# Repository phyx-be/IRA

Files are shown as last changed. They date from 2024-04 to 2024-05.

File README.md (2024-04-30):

# IRA
IRA, named after the [mother of the stars in Polynesisn mythology](https://en.wikipedia.org/wiki/Ira_(mythology)) is the controller for the lights at [Fri3d Camp](https://fri3d.be/) based around the ESP-WROVER-32. The design was made to fit in the [Hammond 1593ARTBU](https://www.hammfg.com/part/1593ARTBU?referer=741) housing.

## REV 00
Initial prototype of the IRA controller.

## REV 01
Production version of the IRA, most of the boards have 2 buffered outputs, 20 have been fitted with RS-485 hardware for DMX. Changes compared to REV 00 : Added clearance around screw holes, added text around switches and increased documentation on silk layers.

## REV 02
Modified version of the 01 revision with less free IO but 8 buffered outputs for WS2812-style adressable LEDs. 12V power has been upgraded to a switching power supply and 2 soldered threaded standoffs are added which can be used as power distribution points. The expansion header has all the pins for I²C or I²S expansions. Onboard I²C has been removed and a [Tag-Connect](https://www.tag-connect.com/product/tc2030-idc-nl) programming header was added. 

There are various stuffing options : 
- Default : 12V or 5V Power, 8 buffered outputs
- Default DMX : 12V or 5V Power, 8 buffered outputs, DMX
- Minimal : 5V Power, 2 buffered outputs
- Minimal DMX : 5V Power, 2 buffered outputs, DMX
- Development : 12V or 5V Power, 8 buffered outputs, DMX, USB Serial convertor with USB-C connector

# Pictures

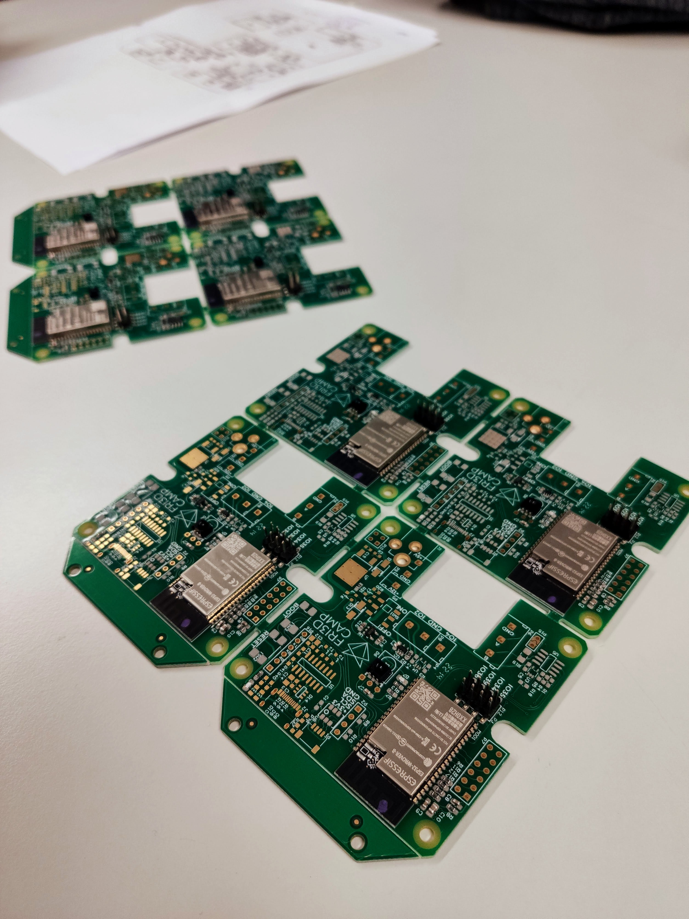
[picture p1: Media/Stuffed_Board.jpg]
IRA Stuffed Boards

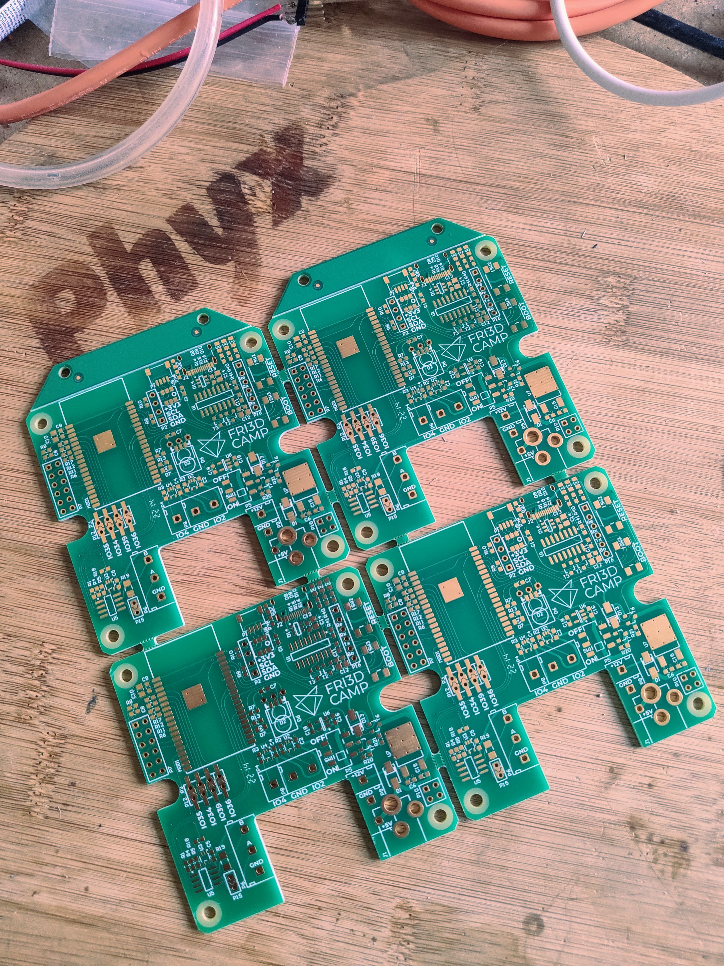
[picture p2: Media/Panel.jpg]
IRA Panel

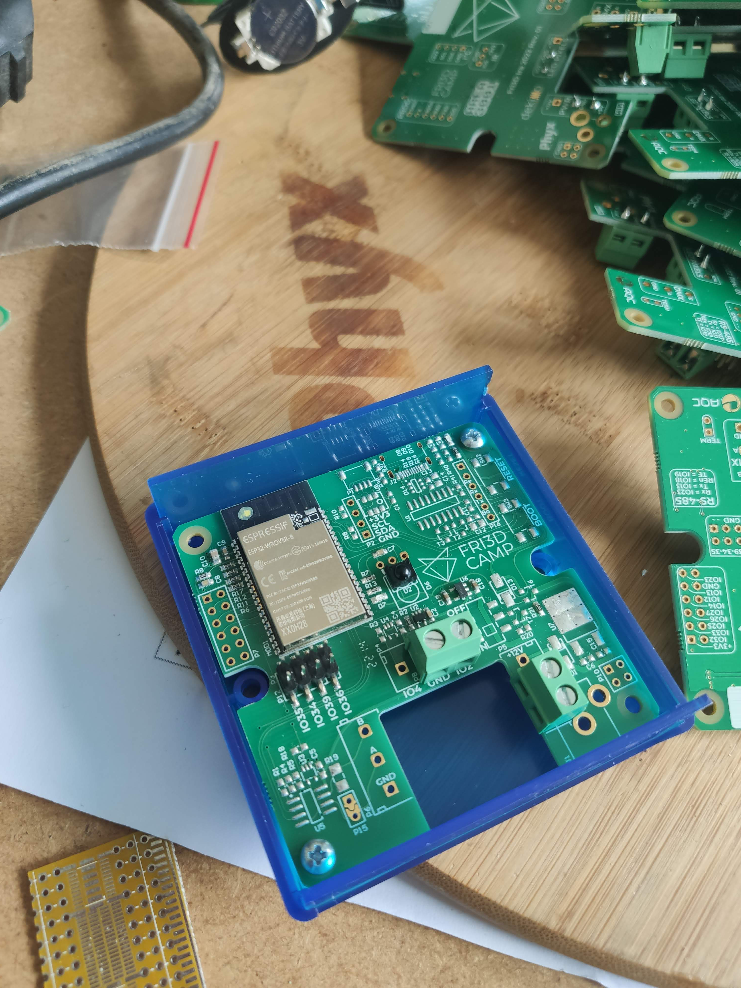
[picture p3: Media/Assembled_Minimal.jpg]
IRA Assembled

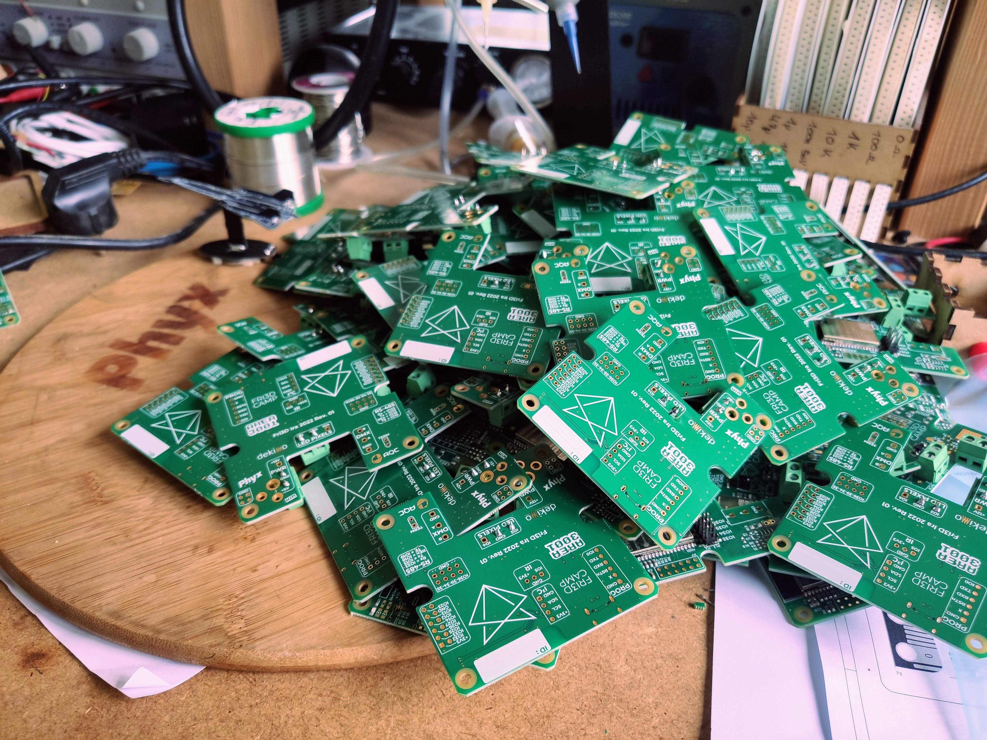
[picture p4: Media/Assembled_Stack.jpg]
IRA Assembled Stack


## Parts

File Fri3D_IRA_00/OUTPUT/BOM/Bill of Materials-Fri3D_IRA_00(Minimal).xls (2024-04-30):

Bill of Materials |  |  | Fri3D Ira 2020
Project: |  | Fri3D_IRA_00.PrjPcb
Revision: |  | 00
Variant: |  | Minimal
Creation Date: | 18/09/2021 | 11:14
Print Date: | 2021-09-18 | 11:14:57
Footprint | Comment | LibRef | Designator | Value | Description | Supplier 1 | Supplier Part Number 1 | Supplier 2 | Supplier Part Number 2 | Supplier 3 | Supplier Part Number 3 | Quantity
C0603_N |  | CAP # 100nF 16V 0603 | C2, C7, C8, C9 | 100nF 16V | CAP # 100nF 16V 0603 | LCSC | C282519 |  |  | Generic | 100nF 16V 0603 X7R | 4
C0805_N |  | CAP # 10uF 10V 0805 | C10 | 10uF 10V | CAP # 10uF 10V 0805 | Farnell | 2320859 | LCSC | C17024 | Generic | 10uF 10V 0805 X7R | 1
C0603_N |  | CAP # 1uF 16V 0603 | C18, C19 | 1uF 16V | CAP # 1uF 16V 0603 | Farnell | 2320814 |  |  | Generic | 1uF 16V 0603 X7R | 2
CHAU_ZIRM-5042B-42-Z2 | ZIRM-5042B-42-Z2 Infrared Receiver 38 kHz 45° 2.7-5.5V 940nm | PHO IR Rx 940nm ZIRM-5042B-42-Z2 | D2 | ZIRM-5042B-42-Z2 | PHO IR Rx 940nm ZIRM-5042B-42-Z2 | LCSC | C575386 |  |  |  |  | 1
LED_0805_RD | Default 0805 Red LED | LED # Red 0805 | D7 |  | LED # Red 0805 | Farnell | 2099236 |  |  |  |  | 1
LED_0805_GR | Default 0805 Green LED | LED # Green 0805 | D10 |  | LED # Green 0805 | Farnell | 2099239 |  |  |  |  | 1
ESP-WROVER-32 | ESP-32 based ESP-WROVER-32 | WiFi # MOD ESP-WROVER-32 | MOD1 | ESP-WROVER-32 | WiFi # MOD ESP-WROVER-32 | Espressif | ESP-WROVER-32 |  |  |  |  | 1
HDR2X4 | Header 4x2 | Pin Header 2.54mm dual row 8way | P3 |  | Pin Header 2.54mm dual row 8way |  |  |  |  |  |  | 1
TERM_BLK-0508-2-90 | 2 Way Screw HDR 5,08mm | Terminal Block 5.08mm 2way | P8, P9 | PM5.08/2/90 | Terminal Block 5.08mm 2way | Farnell | 1131853 |  |  |  |  | 2
SOLDER_SW_V_1MM | Easy to solder connection | SOLDER SW V 1MM | P11, P17, P18, P19 | NO BOM | SOLDER SW V 1MM |  |  |  |  |  |  | 4
HDR1X6 | Header 6 | Pin Header 2.54mm 6way | P16 |  | Pin Header 2.54mm 6way |  |  |  |  |  |  | 1
R0603_N |  | RES # 1K2 0603 | R2, R13, R16 | 1K2 | RES # 1K2 0603 | Farnell | 2446592 |  |  | Generic | 1K2 1% 0603 | 3
R0603_N |  | RES # 5K1 0603 | R7, R8 | 5K1 | RES # 5K1 0603 | Farnell | 2845922 | LCSC | C112314 | Generic | 5K1 1% 0603 | 2
R0603_N |  | RES # 0R 0603 | R21 | 0R | RES # 0R 0603 | Farnell | 2447743 |  |  | Generic | 0R 1% 0603 | 1
TI_DCK_R-PDSO-G5 | SN74AHCT1G125DCKR Buffer, Tri-State, 4.5V to 5.5V | BUF # 1 SN74AHCT1G125DCKR | U2 | SN74AHCT1G125DCKR | BUF # 1 SN74AHCT1G125DCKR | LCSC | C151417 | LCSC | C350557 |  |  | 1
SOT23-5 | 3V3 LDO 700mA 50mV | LDO # 3V3 XC6210B33 | U6 | XC6210B332MR | LDO # 3V3 XC6210B33 | Farnell | 1057803 | LCSC | C47719 |  |  | 1
 |  |  |  |  |  |  |  |  |  |  |  | 27
Approved |  | Notes

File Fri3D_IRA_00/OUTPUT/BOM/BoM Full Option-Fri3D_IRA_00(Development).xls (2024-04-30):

Bill of Materials |  |  | Fri3D Ira 2020
Project: |  | Fri3D_IRA_00.PrjPcb
Revision: |  | 00
Variant: |  | Development
Creation Date: | 18/09/2021 | 11:15
Print Date: | 2021-09-19 | 12:49:20
Footprint | Comment | LibRef | Designator | Value | Description | Supplier 1 | Supplier Part Number 1 | Supplier 2 | Supplier Part Number 2 | Supplier 3 | Supplier Part Number 3 | Quantity | 10
C0603_N |  | CAP # 100nF 16V 0603 | C1, C2, C4, C5, C7, C8, C9, C11, C13 | 100nF 16V | CAP # 100nF 16V 0603 | LCSC | C282519 |  |  | Generic | 100nF 16V 0603 X7R | 9 | 90 | C282519
C0603_N |  | CAP # 1uF 16V 0603 | C6, C15, C18, C19 | 1uF 16V | CAP # 1uF 16V 0603 | Farnell | 2320814 |  |  | Generic | 1uF 16V 0603 X7R | 4 | 40
C0805_N |  | CAP # 10uF 10V 0805 | C10, C12, C14 | 10uF 10V | CAP # 10uF 10V 0805 | Farnell | 2320859 | LCSC | C17024 | Generic | 10uF 10V 0805 X7R | 3 | 30 | C17024
SMA_AC | MBRA210LT3G Schottky Power Rectifier, 2A, 10V | Schottky # MBRA210LT3G | D1, D13 | MBRA210LT3G | Schottky # MBRA210LT3G | LCSC | C145190 |  |  |  |  | 2 | 20 | C145190
CHAU_ZIRM-5042B-42-Z2 | ZIRM-5042B-42-Z2 Infrared Receiver 38 kHz 45° 2.7-5.5V 940nm | PHO IR Rx 940nm ZIRM-5042B-42-Z2 | D2 | ZIRM-5042B-42-Z2 | PHO IR Rx 940nm ZIRM-5042B-42-Z2 | LCSC | C575386 |  |  |  |  | 1 | 10 | C575386
LED_0805_RD | Default 0805 Red LED | LED # Red 0805 | D7, D8 |  | LED # Red 0805 | Farnell | 2099236 |  |  |  |  | 2 | 20
LED_0805_GR | Default 0805 Green LED | LED # Green 0805 | D9, D10 |  | LED # Green 0805 | Farnell | 2099239 |  |  |  |  | 2 | 20
NXP_SOT457 | TVS Diode Dual USB | TVS # IP4220CZ6 Dual USB | D14 | IP4220CZ6 | TVS # IP4220CZ6 Dual USB | Farnell | 1506629 |  |  |  |  | 1 | 10
HRO_TYPE-C-31-M-12 | USB 2.0 C Reversible Receptacle Horizontal | USB # C 2.0 RCPT TYPE-C-31-M-12 | J2 | TYPE-C-31-M-12 | USB # C 2.0 RCPT TYPE-C-31-M-12 | China | HRO TYPE-C-31-M-12 | LCSC | C165948 | LCSC ALT | C167321 / C319148 | 1 | 10 | C165948
ESP-WROVER-32 | ESP-32 based ESP-WROVER-32 | WiFi # MOD ESP-WROVER-32 | MOD1 | ESP-WROVER-32 | WiFi # MOD ESP-WROVER-32 | Espressif | ESP-WROVER-32 |  |  |  |  | 1 | 10
WE_665104131822 | Header 1.0mm RA Shrouded 4 | HDR # RA SHR 1.0mm 4way - 665104131822 | P1 | 665104131822 | HDR # RA SHR 1.0mm 4way - 665104131822 | Wurth | 665104131822 | Mouser | 710-665104131822 |  |  | 1 | 10
HDR2X4 | Header 4x2 | Pin Header 2.54mm dual row 8way | P3 |  | Pin Header 2.54mm dual row 8way |  |  |  |  |  |  | 1 | 10
TERM_BLK-0508-3-90 | 3 Way Screw HDR 5,08mm | Terminal Block 5.08mm 3way | P4, P5, P6 | PM5.08/3/90 | Terminal Block 5.08mm 3way | Farnell |  |  |  |  |  | 3 | 30
HDR2X6 | Header 6X2 | Pin Header 2.54mm dual row 12way | P7 |  | Pin Header 2.54mm dual row 12way |  |  |  |  |  |  | 1 | 10
HDR2X2 | Header 2X2 | Pin Header 2.54mm dual row 4way | P10 |  | Pin Header 2.54mm dual row 4way |  |  |  |  |  |  | 1 | 10
SOLDER_SW_V_1MM | Easy to solder connection | SOLDER SW V 1MM | P11, P14, P17, P18, P19 | NO BOM | SOLDER SW V 1MM |  |  |  |  |  |  | 5 | 50
HDR1X2 | Header 2 | Pin Header 2.54mm 2way | P15 |  | Pin Header 2.54mm 2way |  |  |  |  |  |  | 1 | 10
R0603_N |  | RES # 5K1 0603 | R1, R4, R5, R7, R8, R9, R10, R37, R38 | 5K1 | RES # 5K1 0603 | Farnell | 2845922 | LCSC | C112314 | Generic | 5K1 1% 0603 | 9 | 90 | C112314
R0603_N |  | RES # 1K2 0603 | R2, R3, R13, R14, R15, R16 | 1K2 | RES # 1K2 0603 | Farnell | 2446592 |  |  | Generic | 1K2 1% 0603 | 6 | 60
R1206 |  | RES # 120R 1206 | R19 | 120R | RES # 120R 1206 |  |  |  |  | Generic | 120R 1% 1206 | 1 | 10
R0603_N |  | RES # 0R 0603 | R22, R23 | 0R | RES # 0R 0603 | Farnell | 2447743 |  |  | Generic | 0R 1% 0603 | 2 | 20
R0603_N |  | RES # 100R 0603 | R40, R41 | 100R | RES # 100R 0603 | Farnell | 2446544 |  |  | Generic | 100R 1% 0603 | 2 | 20
MSS22D18 | Mini slide switch 2P2T | SW # 2P2T mini slide MSS22D18 | SW1 | MSS22D18 | SW # 2P2T mini slide MSS22D18 | LCSC | C381098 | LCSC | C145845 | AliExpress | MSS22D18 | 1 | 10 | C381098
WE_430181038816 | 4.5x4.5mm tact SMD H3,8mm | SW # TACT small 4.5x4.5mm SMD WS-TASV | SW2, SW3 | 430181038816 | SW # TACT small 4.5x4.5mm SMD WS-TASV | Wurth | 430181038816 | Mouser | 710-430181038816 | LCSC | C174049 | 2 | 20 | C174049
SOT23-3 | 0.2A N-Ch MOSFET Vgs 3.2 | BSS138 N-Ch MOSFET 0.2A 3.2Vgs 60Vds | T2, T3 | BSS138 | BSS138 N-Ch MOSFET 0.2A 3.2Vgs 60Vds | Farnell | 2432717 | LCSC | C426569 |  |  | 2 | 20 | C426569
SOT23-3 | -2.3A -20V P-Ch MOSFET Vgs -1V | SL2301 P-Ch MOSFET -2.3A -20Vds | T6, T7 | SL2301 | SL2301 P-Ch MOSFET -2.3A -20Vds | LCSC | C181086 |  |  |  |  | 2 | 20 | C181086
SOIC_N_16 | USB to full UART with internal crystal | CH340C # UCB UART | U1 | CH340C | CH340C # UCB UART | LCSC | C84681 |  |  |  |  | 1 | 10 | C84681
TI_DCK_R-PDSO-G5 | SN74AHCT1G125DCKR Buffer, Tri-State, 4.5V to 5.5V | BUF # 1 SN74AHCT1G125DCKR | U2, U4 | SN74AHCT1G125DCKR | BUF # 1 SN74AHCT1G125DCKR | LCSC | C151417 | LCSC | C350557 |  |  | 2 | 20 | C151417
SOIC_N_8 | RS-485 5V Transceiver | MAX485 # RS-485 transceiver | U5 | MAX485ECSA+ | MAX485 # RS-485 transceiver | Farnell | 9724524 | LCSC | C2691412 |  |  | 1 | 10 | C2691412
SOT23-5 | 3V3 LDO 700mA 50mV | LDO # 3V3 XC6210B33 | U6 | XC6210B332MR | LDO # 3V3 XC6210B33 | Farnell | 1057803 | LCSC | C47719 |  |  | 1 | 10 | C47719
TO-252 |  | PWR # 78M05 5V LDO TO252 | U7 | 78M05 | PWR # 78M05 5V LDO TO252 |  |  |  |  |  |  | 1 | 10 | C183889
 |  |  |  |  |  |  |  |  |  |  |  | 72
Approved |  | Notes

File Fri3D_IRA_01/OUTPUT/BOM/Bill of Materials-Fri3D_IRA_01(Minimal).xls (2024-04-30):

Bill of Materials |  |  | Fri3D Ira 2022
Project: |  | Fri3D_IRA_01.PrjPcb
Revision: |  | 01
Variant: |  | Minimal
Creation Date: | 01/06/2022 | 19:35
Print Date: | 2022-06-01 | 19:35:58
Footprint | Comment | LibRef | Designator | Value | Description | Supplier 1 | Supplier Part Number 1 | Supplier 2 | Supplier Part Number 2 | Supplier 3 | Supplier Part Number 3 | Quantity
C0603_N |  | CAP # 100nF 16V 0603 | C2, C7, C8, C9 | 100nF 16V | CAP # 100nF 16V 0603 | LCSC | C282519 |  |  | Generic | 100nF 16V 0603 X7R | 4
C0805_N |  | CAP # 10uF 10V 0805 | C10 | 10uF 10V | CAP # 10uF 10V 0805 | Farnell | 2320859 | LCSC | C17024 | Generic | 10uF 10V 0805 X7R | 1
C0603_N |  | CAP # 1uF 16V 0603 | C18, C19 | 1uF 16V | CAP # 1uF 16V 0603 | Farnell | 2320814 |  |  | Generic | 1uF 16V 0603 X7R | 2
CHAU_ZIRM-5042B-42-Z2 | ZIRM-5042B-42-Z2 Infrared Receiver 38 kHz 45° 2.7-5.5V 940nm | PHO IR Rx 940nm ZIRM-5042B-42-Z2 | D2 | ZIRM-5042B-42-Z2 | =Description | LCSC | C575386 |  |  |  |  | 1
LED_0805_GR | Default 0805 Green LED | LED # Green 0805 | D7, D10 |  | LED # Green 0805 | Farnell | 2099239 |  |  |  |  | 2
ESP-WROVER-32 | ESP-32 based ESP-WROVER-32 | WiFi # MOD ESP-WROVER-32 | MOD1 | ESP-WROVER-32 | WiFi # MOD ESP-WROVER-32 | Espressif | ESP-WROVER-32 |  |  |  |  | 1
HDR2X4 | Header 4x2 | Pin Header 2.54mm dual row 8way | P3 |  | Pin Header 2.54mm dual row 8way |  |  |  |  |  |  | 1
TERM_BLK-0508-2-90 | 2 Way Screw HDR 5,08mm | Terminal Block 5.08mm 2way | P8, P9 | PM5.08/2/90 | Terminal Block 5.08mm 2way | Farnell | 1131853 | LCSC | C8465 |  |  | 2
SOLDER_SW_V_1MM | Easy to solder connection | SOLDER SW V 1MM | P11, P17, P18, P19 | NO BOM | SOLDER SW V 1MM |  |  |  |  |  |  | 4
HDR2X3_SMD | Header 3X2 | Pin Header # 2.54mm dual row 6way | P12 |  | Pin Header # 2.54mm dual row 6way | LCSC | C192301 | LCSC | C124390 |  |  | 1
HDR1X6 | Header 6 | Pin Header 2.54mm 6way | P16 |  | Pin Header 2.54mm 6way |  |  |  |  |  |  | 1
R0603_N |  | RES # 1K2 0603 | R2, R13, R16 | 1K2 | RES # 1K2 0603 | Farnell | 2446592 |  |  | Generic | 1K2 1% 0603 | 3
R0603_N |  | RES # 5K1 0603 | R6, R7, R8, R11, R12, R17 | 5K1 | RES # 5K1 0603 | Farnell | 2845922 | LCSC | C112314 | Generic | 5K1 1% 0603 | 6
R0603_N |  | RES # 0R 0603 | R21 | 0R | RES # 0R 0603 | Farnell | 2447743 | LCSC | C95177 | Generic | 0R 1% 0603 | 1
TI_DCK_R-PDSO-G5 | SN74AHCT1G125DCKR Buffer, Tri-State, 4.5V to 5.5V | BUF # 1 SN74AHCT1G125DCKR | U2 | SN74AHCT1G125DCKR | BUF # 1 SN74AHCT1G125DCKR | LCSC | C151417 | LCSC | C350557 |  |  | 1
SOT23-5 | 3V3 LDO 700mA 50mV | LDO # 3V3 XC6210B33 | U6 | XC6210B332MR | LDO # 3V3 XC6210B33 | Farnell | 1057803 | LCSC | C47719 |  |  | 1
 |  |  |  |  |  |  |  |  |  |  |  | 32
Approved |  | Notes

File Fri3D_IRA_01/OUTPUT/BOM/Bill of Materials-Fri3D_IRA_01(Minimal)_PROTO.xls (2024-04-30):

Bill of Materials |  | Fri3D Ira 2022
Project: | Fri3D_IRA_01.PrjPcb
Revision: | 01
Variant: | Minimal
Creation Date: | 09:29
Print Date: | 14:42:48
Footprint | LibRef | Designator | Value | Description | Quantity
C0603_N | CAP # 100nF 16V 0603 | C2, C7, C8, C9 | 100nF 16V | CAP # 100nF 16V 0603 | 4
C0805_N | CAP # 10uF 10V 0805 | C10 | 10uF 10V | CAP # 10uF 10V 0805 | 1
C0603_N | CAP # 1uF 16V 0603 | C18, C19 | 1uF 16V | CAP # 1uF 16V 0603 | 2
CHAU_ZIRM-5042B-42-Z2 | PHO IR Rx 940nm ZIRM-5042B-42-Z2 | D2 | ZIRM-5042B-42-Z2 |  | 1
LED_0805_GR | LED # Green 0805 | D7, D10 |  | LED # Green 0805 | 2
ESP-WROVER-32 | WiFi # MOD ESP-WROVER-32 | MOD1 | ESP-WROVER-32 | WiFi # MOD ESP-WROVER-32 | 1
TERM_BLK-0508-2-90 | Terminal Block 5.08mm 2way | P8, P9 | PM5.08/2/90 | Terminal Block 5.08mm 2way | 2
HDR2X3_SMD | Pin Header # 2.54mm dual row 6way | P12 |  | Pin Header # 2.54mm dual row 6way | 1
R0603_N | RES # 1K2 0603 | R2, R13, R16 | 1K2 | RES # 1K2 0603 | 3
R0603_N | RES # 5K1 0603 | R6, R7, R8, R11, R12, R17 | 5K1 | RES # 5K1 0603 | 6
R0603_N | RES # 0R 0603 | R21 | 0R | RES # 0R 0603 | 1
TI_DCK_R-PDSO-G5 | BUF # 1 SN74AHCT1G125DCKR | U2 | SN74AHCT1G125DCKR | BUF # 1 SN74AHCT1G125DCKR | 1
SOT23-5 | LDO # 3V3 XC6210B33 | U6 | XC6210B332MR | LDO # 3V3 XC6210B33 | 1
 |  |  |  |  | 26

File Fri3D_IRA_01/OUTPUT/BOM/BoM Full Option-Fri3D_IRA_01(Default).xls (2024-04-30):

Bill of Materials |  |  | Fri3D Ira 2022
Project: |  | Fri3D_IRA_01.PrjPcb
Revision: |  | 01
Variant: |  | Default
Creation Date: | 19/04/2022 | 17:24
Print Date: | 2022-04-19 | 17:24:49
Footprint | Comment | LibRef | Designator | Value | Description | Supplier 1 | Supplier Part Number 1 | Supplier 2 | Supplier Part Number 2 | Supplier 3 | Supplier Part Number 3 | Quantity
C0603_N |  | CAP # 100nF 16V 0603 | C1, C2, C4, C5, C7, C8, C9, C11, C13 | 100nF 16V | CAP # 100nF 16V 0603 | LCSC | C282519 |  |  | Generic | 100nF 16V 0603 X7R | 9
C0805_N |  | CAP # 10uF 10V 0805 | C10, C12, C14 | 10uF 10V | CAP # 10uF 10V 0805 | Farnell | 2320859 | LCSC | C17024 | Generic | 10uF 10V 0805 X7R | 3
C0603_N |  | CAP # 1uF 16V 0603 | C18, C19 | 1uF 16V | CAP # 1uF 16V 0603 | Farnell | 2320814 |  |  | Generic | 1uF 16V 0603 X7R | 2
CHAU_ZIRM-5042B-42-Z2 | ZIRM-5042B-42-Z2 Infrared Receiver 38 kHz 45° 2.7-5.5V 940nm | PHO IR Rx 940nm ZIRM-5042B-42-Z2 | D2 | ZIRM-5042B-42-Z2 | =Description | LCSC | C575386 |  |  |  |  | 1
LED_0805_GR | Default 0805 Green LED | LED # Green 0805 | D7, D9, D10 |  | LED # Green 0805 | Farnell | 2099239 |  |  |  |  | 3
LED_0805_RD | Default 0805 Red LED | LED # Red 0805 | D8 |  | LED # Red 0805 | Farnell | 2099236 |  |  |  |  | 1
NXP_SOT457 | TVS Diode Dual USB | TVS # IP4220CZ6 Dual USB | D14 | IP4220CZ6 | TVS # IP4220CZ6 Dual USB | Farnell | 1506629 |  |  |  |  | 1
HRO_TYPE-C-31-M-12 | USB 2.0 C Reversible Receptacle Horizontal | USB # C 2.0 RCPT TYPE-C-31-M-12 | J2 | TYPE-C-31-M-12 | USB # C 2.0 RCPT TYPE-C-31-M-12 | China | HRO TYPE-C-31-M-12 | LCSC | C165948 | LCSC ALT | C167321 / C319148 | 1
ESP-WROVER-32 | ESP-32 based ESP-WROVER-32 | WiFi # MOD ESP-WROVER-32 | MOD1 | ESP-WROVER-32 | WiFi # MOD ESP-WROVER-32 | Espressif | ESP-WROVER-32 |  |  |  |  | 1
HDR2X4 | Header 4x2 | Pin Header 2.54mm dual row 8way | P3 |  | Pin Header 2.54mm dual row 8way |  |  |  |  |  |  | 1
TERM_BLK-0508-3-90 | 3 Way Screw HDR 5,08mm | Terminal Block 5.08mm 3way | P4, P6 | PM5.08/3/90 | Terminal Block 5.08mm 3way | Farnell |  |  |  |  |  | 2
TERM_BLK-0508-2-90 | 2 Way Screw HDR 5,08mm | Terminal Block 5.08mm 2way | P9 | PM5.08/2/90 | Terminal Block 5.08mm 2way | Farnell | 1131853 | LCSC | C8465 |  |  | 1
SOLDER_SW_V_1MM | Easy to solder connection | SOLDER SW V 1MM | P11, P14, P17, P18, P19 | NO BOM | SOLDER SW V 1MM |  |  |  |  |  |  | 5
HDR2X3_SMD | Header 3X2 | Pin Header # 2.54mm dual row 6way | P12 |  | Pin Header # 2.54mm dual row 6way | LCSC | C192301 | LCSC | C124390 |  |  | 1
HDR1X2 | Header 2 | Pin Header 2.54mm 2way | P15 |  | Pin Header 2.54mm 2way | LCSC | C492401 | LCSC | C541856 |  |  | 1
R0603_N |  | RES # 5K1 0603 | R1, R4, R5, R6, R7, R8, R9, R10, R11, R12, R17, R37, R38 | 5K1 | RES # 5K1 0603 | Farnell | 2845922 | LCSC | C112314 | Generic | 5K1 1% 0603 | 13
R0603_N |  | RES # 1K2 0603 | R2, R3, R13, R14, R15, R16 | 1K2 | RES # 1K2 0603 | Farnell | 2446592 |  |  | Generic | 1K2 1% 0603 | 6
R1206 |  | RES # 120R 1206 | R19 | 120R | RES # 120R 1206 |  |  |  |  | Generic | 120R 1% 1206 | 1
R0603_N |  | RES # 0R 0603 | R21 | 0R | RES # 0R 0603 | Farnell | 2447743 | LCSC | C95177 | Generic | 0R 1% 0603 | 1
R0603_N |  | RES # 100R 0603 | R40, R41 | 100R | RES # 100R 0603 | Farnell | 2446544 |  |  | Generic | 100R 1% 0603 | 2
WE_430181038816 | 4.5x4.5mm tact SMD H3,8mm | SW # TACT small 4.5x4.5mm SMD WS-TASV | SW2, SW3 | 430181038816 | SW # TACT small 4.5x4.5mm SMD WS-TASV | Wurth | 430181038816 | Mouser | 710-430181038816 | LCSC | C174049 | 2
SOT23-3 | 0.2A N-Ch MOSFET Vgs 3.2 | BSS138 N-Ch MOSFET 0.2A 3.2Vgs 60Vds | T2, T3 | BSS138 | BSS138 N-Ch MOSFET 0.2A 3.2Vgs 60Vds | Farnell | 2432717 | LCSC | C426569 |  |  | 2
SOIC_N_16 | USB to full UART with internal crystal | CH340C # UCB UART | U1 | CH340C | CH340C # UCB UART | LCSC | C84681 |  |  |  |  | 1
TI_DCK_R-PDSO-G5 | SN74AHCT1G125DCKR Buffer, Tri-State, 4.5V to 5.5V | BUF # 1 SN74AHCT1G125DCKR | U2, U3, U4 | SN74AHCT1G125DCKR | BUF # 1 SN74AHCT1G125DCKR | LCSC | C151417 | LCSC | C350557 |  |  | 3
SOIC_N_8 | RS-485 5V Transceiver | MAX485 # RS-485 transceiver | U5 | MAX485ECSA+ | MAX485 # RS-485 transceiver | Farnell | 9724524 |  |  |  |  | 1
SOT23-5 | 3V3 LDO 700mA 50mV | LDO # 3V3 XC6210B33 | U6 | XC6210B332MR | LDO # 3V3 XC6210B33 | Farnell | 1057803 | LCSC | C47719 |  |  | 1
AHT10 | AHT 10 Temperature and humidity sensor | TMP HUM # AHT10 | U8 | AHT10 | TMP HUM # AHT10 | LCSC | C368909 |  |  |  |  | 1
 |  |  |  |  |  |  |  |  |  |  |  | 67
Approved |  | Notes

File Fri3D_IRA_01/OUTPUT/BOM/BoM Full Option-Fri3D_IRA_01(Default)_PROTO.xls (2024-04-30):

Bill of Materials |  | Fri3D Ira 2022
Project: | Fri3D_IRA_01.PrjPcb
Revision: | 01
Variant: | Default
Creation Date: | 17:24
Print Date: | 11:26:54
Footprint | LibRef | Designator | Value | Description | Quantity
C0603_N | CAP # 100nF 16V 0603 | C1, C2, C4, C5, C7, C8, C9, C11, C13 | 100nF 16V | CAP # 100nF 16V 0603 | 9
C0805_N | CAP # 10uF 10V 0805 | C10, C12, C14 | 10uF 10V | CAP # 10uF 10V 0805 | 3
C0603_N | CAP # 1uF 16V 0603 | C18, C19 | 1uF 16V | CAP # 1uF 16V 0603 | 2
CHAU_ZIRM-5042B-42-Z2 | PHO IR Rx 940nm ZIRM-5042B-42-Z2 | D2 | ZIRM-5042B-42-Z2 |  | 1
LED_0805_GR | LED # Green 0805 | D7, D9, D10 |  | LED # Green 0805 | 3
LED_0805_RD | LED # Red 0805 | D8 |  | LED # Red 0805 | 1
NXP_SOT457 | TVS # IP4220CZ6 Dual USB | D14 | IP4220CZ6 | TVS # IP4220CZ6 Dual USB | 1
HRO_TYPE-C-31-M-12 | USB # C 2.0 RCPT TYPE-C-31-M-12 | J2 | TYPE-C-31-M-12 | USB # C 2.0 RCPT TYPE-C-31-M-12 | 1
ESP-WROVER-32 | WiFi # MOD ESP-WROVER-32 | MOD1 | ESP-WROVER-32 | WiFi # MOD ESP-WROVER-32 | 1
HDR2X4 | Pin Header 2.54mm dual row 8way | P3 |  | Pin Header 2.54mm dual row 8way | 1
TERM_BLK-0508-3-90 | Terminal Block 5.08mm 3way | P4, P6 | PM5.08/3/90 | Terminal Block 5.08mm 3way | 2
TERM_BLK-0508-2-90 | Terminal Block 5.08mm 2way | P9 | PM5.08/2/90 | Terminal Block 5.08mm 2way | 1
SOLDER_SW_V_1MM | SOLDER SW V 1MM | P11, P14, P17, P18, P19 | NO BOM | SOLDER SW V 1MM | 5
HDR2X3_SMD | Pin Header # 2.54mm dual row 6way | P12 |  | Pin Header # 2.54mm dual row 6way | 1
HDR1X2 | Pin Header 2.54mm 2way | P15 |  | Pin Header 2.54mm 2way | 1
R0603_N | RES # 5K1 0603 | R1, R4, R5, R6, R7, R8, R9, R10, R11, R12, R17, R37, R38 | 5K1 | RES # 5K1 0603 | 13
R0603_N | RES # 1K2 0603 | R2, R3, R13, R14, R15, R16 | 1K2 | RES # 1K2 0603 | 6
R1206 | RES # 120R 1206 | R19 | 120R | RES # 120R 1206 | 1
R0603_N | RES # 0R 0603 | R21 | 0R | RES # 0R 0603 | 1
R0603_N | RES # 100R 0603 | R40, R41 | 100R | RES # 100R 0603 | 2
WE_430181038816 | SW # TACT small 4.5x4.5mm SMD WS-TASV | SW2, SW3 | 430181038816 | SW # TACT small 4.5x4.5mm SMD WS-TASV | 2
SOT23-3 | BSS138 N-Ch MOSFET 0.2A 3.2Vgs 60Vds | T2, T3 | BSS138 | BSS138 N-Ch MOSFET 0.2A 3.2Vgs 60Vds | 2
SOIC_N_16 | CH340C # UCB UART | U1 | CH340C | CH340C # UCB UART | 1
TI_DCK_R-PDSO-G5 | BUF # 1 SN74AHCT1G125DCKR | U2, U3, U4 | SN74AHCT1G125DCKR | BUF # 1 SN74AHCT1G125DCKR | 3
SOIC_N_8 | MAX485 # RS-485 transceiver | U5 | MAX485ECSA+ | MAX485 # RS-485 transceiver | 1
SOT23-5 | LDO # 3V3 XC6210B33 | U6 | XC6210B332MR | LDO # 3V3 XC6210B33 | 1
AHT10 | TMP HUM # AHT10 | U8 | AHT10 | TMP HUM # AHT10 | 1
 |  |  |  |  | 67

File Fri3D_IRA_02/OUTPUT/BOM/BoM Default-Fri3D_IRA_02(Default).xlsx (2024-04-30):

Bill of Materials |  |  | Fri3D Ira 2022
Project: |  | Fri3D_IRA_02.PrjPcb
Revision: |  | 02
Variant: |  | Default
Creation Date: | 05/04/2024 | 20:33
Print Date: | 2024-04-05 | 20:33:37
Footprint | Comment | LibRef | Designator | Value | Description | Supplier 1 | Supplier Part Number 1 | Supplier 2 | Supplier Part Number 2 | Supplier 3 | Supplier Part Number 3 | Quantity
C0805_N |  | CAP # 10uF 10V 0805 | C1, C10, C15 | 10uF 10V | CAP # 10uF 10V 0805 | Farnell | 2320859 | LCSC | C17024 | Generic | 10uF 10V 0805 X7R | 3
C0603_N |  | CAP # 100nF 16V 0603 | C2, C3, C4, C7, C8, C9, C11, C12, C16, C17, C20 | 100nF 16V | CAP # 100nF 16V 0603 | LCSC | C282519 |  |  | Generic | 100nF 16V 0603 X7R | 11
C0805_N |  | CAP # 10uF 25V 0805 | C6 | 10uF 25V | CAP # 10uF 25V 0805 | LCSC | C237493 | LCSC | C15850 | Generic | 10uF 25V 0805 X7R | 1
C0603_N |  | CAP # 1uF 16V 0603 | C18, C19 | 1uF 16V | CAP # 1uF 16V 0603 | Farnell | 2320814 | LCSC | C1592 | Generic | 1uF 16V 0603 X7R | 2
ON_SOD-123FL_AC | 30V 1A 350mV@100mA SOD-123 Schottky | Schottky # LMBR130T1G | D1, D13 | LMBR130T1G | Schottky # LMBR130T1G | LCSC | C48974 | LCSC | C917121 |  |  | 2
CHAU_ZIRM-5042B-42-Z2 | ZIRM-5042B-42-Z2 Infrared Receiver 38 kHz 45° 2.7-5.5V 940nm | PHO IR Rx 940nm ZIRM-5042B-42-Z2 | D2 | ZIRM-5042B-42-Z2 | =Description | LCSC | C575386 |  |  |  |  | 1
LED_0805_GR | Default 0805 Green LED | LED # Green 0805 | D7, D10 |  | LED # Green 0805 | Farnell | 2099239 | LCSC | C965815 |  |  | 2
ESP-WROVER-32 | ESP-32 based ESP-WROVER-32 | WiFi # MOD ESP-WROVER-32 | MOD1 | ESP-WROVER-32 | WiFi # MOD ESP-WROVER-32 | Espressif | ESP-WROVER-32 |  |  |  |  | 1
WE_691103110003 | 3 Way Screw HDR 3.5mm Rising Cage | Terminal Block 3.5mm 3way | P4, P8 |  | Terminal Block 3.5mm 3way | LCSC | C784941 | Würth | 691214110003 |  |  | 2
TERM_BLK-0508-3-90 | 3 Way Screw HDR 5,08mm | Terminal Block 5.08mm 3way | P5 | PM5.08/3/90 | Terminal Block 5.08mm 3way | LCSC | C72334 | LCSC | C409163 |  |  | 1
WE_691103110002 | 2 Way Screw HDR 3.5mm Rising Cage | Terminal Block 3.5mm 2way | P10 |  | Terminal Block 3.5mm 2way | LCSC | C784940 | Würth | 691214110002 |  |  | 1
SOLDER_SW_V_1MM | Easy to solder connection | SOLDER SW V 1MM | P11, P17, P18, P19 | NO BOM | SOLDER SW V 1MM |  |  |  |  |  |  | 4
HDR2X4_SMD | Header 4X2 | Pin Header # 2.54mm dual row 8way | P12 |  | Pin Header # 2.54mm dual row 8way | LCSC | C192300 |  |  |  |  | 1
TC2030 | 6 pin tagconnect TC2030 | HDR # TC2030 | P13 | TC2030 | HDR # TC2030 | NO PART |  |  |  |  |  | 1
R0603_N |  | RES # 1K 0603 | R2, R3, R9, R10, R22, R23, R24, R25 | 1K | RES # 1K 0603 | Farnell | 2689409 | LCSC | C21190 | Generic | 1K 1% 0603 | 8
R0603_N |  | RES # 5K1 0603 | R6, R7, R8, R11, R12, R13, R16, R17 | 5K1 | RES # 5K1 0603 | Farnell | 2845922 | LCSC | C112314 | Generic | 5K1 1% 0603 | 8
SOT23-3 | -2.3A -20V P-Ch MOSFET Vgs -1V | SL2301 P-Ch MOSFET -2.3A -20Vds | T6 | SL2301 | SL2301 P-Ch MOSFET -2.3A -20Vds | LCSC | C181086 |  |  |  |  | 1
TI_DCK_R-PDSO-G5 | SN74AHCT1G125DCKR Buffer, Tri-State, 4.5V to 5.5V | BUF # 1 SN74AHCT1G125DCKR | U1, U2, U4, U8, U9, U10, U11, U12 | SN74AHCT1G125DCKR | BUF # 1 SN74AHCT1G125DCKR | LCSC | C151417 | LCSC | C350557 |  |  | 8
SOT23-5 | 3V3 LDO 700mA 50mV | LDO # 3V3 XC6210B33 | U6 | XC6210B332MR | LDO # 3V3 XC6210B33 | Farnell | 1057803 | LCSC | C47719 |  |  | 1
K78xx-500R3-LB | Mornsun K7805-500R3-LB 5V 500mA 4.75~36Vin | PWR MOD Buck 5V K7805-500R3-LB | U7 | K7805-500R3-LB | PWR MOD Buck 5V K7805-500R3-LB | Digi-key | 2725-K7805-500R3-LB-ND | LCSC | C5198056 |  |  | 1
 |  |  |  |  |  |  |  |  |  |  |  | 60
Approved |  | Notes

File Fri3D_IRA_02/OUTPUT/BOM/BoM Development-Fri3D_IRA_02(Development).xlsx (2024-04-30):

Bill of Materials |  |  | Fri3D Ira 2022
Project: |  | Fri3D_IRA_02.PrjPcb
Revision: |  | 02
Variant: |  | Development
Creation Date: | 05/04/2024 | 20:33
Print Date: | 2024-04-05 | 20:33:47
Footprint | Comment | LibRef | Designator | Value | Description | Supplier 1 | Supplier Part Number 1 | Supplier 2 | Supplier Part Number 2 | Supplier 3 | Supplier Part Number 3 | Quantity
C0805_N |  | CAP # 10uF 10V 0805 | C1, C10, C14, C15, C22 | 10uF 10V | CAP # 10uF 10V 0805 | Farnell | 2320859 | LCSC | C17024 | Generic | 10uF 10V 0805 X7R | 5
C0603_N |  | CAP # 100nF 16V 0603 | C2, C3, C4, C5, C7, C8, C9, C11, C12, C13, C16, C17, C20, C21 | 100nF 16V | CAP # 100nF 16V 0603 | LCSC | C282519 |  |  | Generic | 100nF 16V 0603 X7R | 14
C0805_N |  | CAP # 10uF 25V 0805 | C6 | 10uF 25V | CAP # 10uF 25V 0805 | LCSC | C237493 | LCSC | C15850 | Generic | 10uF 25V 0805 X7R | 1
C0603_N |  | CAP # 1uF 16V 0603 | C18, C19 | 1uF 16V | CAP # 1uF 16V 0603 | Farnell | 2320814 | LCSC | C1592 | Generic | 1uF 16V 0603 X7R | 2
ON_SOD-123FL_AC | 30V 1A 350mV@100mA SOD-123 Schottky | Schottky # LMBR130T1G | D1, D13 | LMBR130T1G | Schottky # LMBR130T1G | LCSC | C48974 | LCSC | C917121 |  |  | 2
CHAU_ZIRM-5042B-42-Z2 | ZIRM-5042B-42-Z2 Infrared Receiver 38 kHz 45° 2.7-5.5V 940nm | PHO IR Rx 940nm ZIRM-5042B-42-Z2 | D2 | ZIRM-5042B-42-Z2 | =Description | LCSC | C575386 |  |  |  |  | 1
LED_0805_RD | Default 0805 Red LED | LED # Red 0805 | D3 |  | LED # Red 0805 | Farnell | 2099236 | LCSC | C965812 |  |  | 1
LED_0805_GR | Default 0805 Green LED | LED # Green 0805 | D4, D7, D10 |  | LED # Green 0805 | Farnell | 2099239 | LCSC | C965815 |  |  | 3
HRO_TYPE-C-31-M-12 | USB 2.0 C Reversible Receptacle Horizontal | USB # C 2.0 RCPT TYPE-C-31-M-12 | J1 | TYPE-C-31-M-12 | USB # C 2.0 RCPT TYPE-C-31-M-12 | China | HRO TYPE-C-31-M-12 | LCSC | C165948 | LCSC ALT | C167321 / C319148 | 1
WE_9774010360 | SMD Spacer 1mm M3 Internal Thread | SPACER # M3 1mm | M1, M2 | 9774010360 | SPACER # M3 1mm | Wurth | 9774010360 |  |  |  |  | 2
ESP-WROVER-32 | ESP-32 based ESP-WROVER-32 | WiFi # MOD ESP-WROVER-32 | MOD1 | ESP-WROVER-32 | WiFi # MOD ESP-WROVER-32 | Espressif | ESP-WROVER-32 |  |  |  |  | 1
WE_691103110003 | 3 Way Screw HDR 3.5mm Rising Cage | Terminal Block 3.5mm 3way | P4, P6, P8 |  | Terminal Block 3.5mm 3way | LCSC | C784941 | Würth | 691214110003 |  |  | 3
TERM_BLK-0508-3-90 | 3 Way Screw HDR 5,08mm | Terminal Block 5.08mm 3way | P5 | PM5.08/3/90 | Terminal Block 5.08mm 3way | LCSC | C72334 | LCSC | C409163 |  |  | 1
HDR2X3 | Header 3X2 | Pin Header 2.54mm dual row 6way | P7 |  | Pin Header 2.54mm dual row 6way |  |  |  |  |  |  | 1
WE_691103110002 | 2 Way Screw HDR 3.5mm Rising Cage | Terminal Block 3.5mm 2way | P10 |  | Terminal Block 3.5mm 2way | LCSC | C784940 | Würth | 691214110002 |  |  | 1
SOLDER_SW_V_1MM | Easy to solder connection | SOLDER SW V 1MM | P11, P14, P17, P18, P19 | NO BOM | SOLDER SW V 1MM |  |  |  |  |  |  | 5
HDR2X4_SMD | Header 4X2 | Pin Header # 2.54mm dual row 8way | P12 |  | Pin Header # 2.54mm dual row 8way | LCSC | C192300 |  |  |  |  | 1
HDR1X2 | Header 2 | Pin Header 2.54mm 2way | P15 |  | Pin Header 2.54mm 2way | LCSC | C492401 | LCSC | C541856 |  |  | 1
R0603_N |  | RES # 5K1 0603 | R1, R4, R5, R6, R7, R8, R11, R12, R13, R16, R17, R20, R26, R27, R28 | 5K1 | RES # 5K1 0603 | Farnell | 2845922 | LCSC | C112314 | Generic | 5K1 1% 0603 | 15
R0603_N |  | RES # 1K 0603 | R2, R3, R9, R10, R22, R23, R24, R25 | 1K | RES # 1K 0603 | Farnell | 2689409 | LCSC | C21190 | Generic | 1K 1% 0603 | 8
R0603_N |  | RES # 100R 0603 | R14, R15 | 100R | RES # 100R 0603 | Farnell | 2446544 | LCSC | C22775 | Generic | 100R 1% 0603 | 2
R1206 |  | RES # 120R 1206 | R19 | 120R | RES # 120R 1206 | LCSC | C17909 |  |  | Generic | 120R 1% 1206 | 1
WE_430181038816 | 4.5x4.5mm tact SMD H3,8mm | SW # TACT small 4.5x4.5mm SMD WS-TASV | SW2, SW3 | 430181038816 | SW # TACT small 4.5x4.5mm SMD WS-TASV | Wurth | 430181038816 | Mouser | 710-430181038816 | LCSC | C174049 | 2
SOT23-3 | 0.2A N-Ch MOSFET Vgs 3.2 | BSS138 N-Ch MOSFET 0.2A 3.2Vgs 60Vds | T1, T2 | BSS138 |  | Farnell | 2432717 |  |  |  |  | 2
SOT23-3 | -2.3A -20V P-Ch MOSFET Vgs -1V | SL2301 P-Ch MOSFET -2.3A -20Vds | T6 | SL2301 | SL2301 P-Ch MOSFET -2.3A -20Vds | LCSC | C181086 |  |  |  |  | 1
TI_DCK_R-PDSO-G5 | SN74AHCT1G125DCKR Buffer, Tri-State, 4.5V to 5.5V | BUF # 1 SN74AHCT1G125DCKR | U1, U2, U3, U4, U8, U9, U10, U11, U12 | SN74AHCT1G125DCKR | BUF # 1 SN74AHCT1G125DCKR | LCSC | C151417 | LCSC | C350557 |  |  | 9
SOIC_N_8 | RS-485 5V Transceiver 500kbps | WS3085 # RS-485 transceiver | U5 | WS3085 | WS3085 # RS-485 transceiver | LCSC | C2691412 |  |  |  |  | 1
SOT23-5 | 3V3 LDO 700mA 50mV | LDO # 3V3 XC6210B33 | U6 | XC6210B332MR | LDO # 3V3 XC6210B33 | Farnell | 1057803 | LCSC | C47719 |  |  | 1
K78xx-500R3-LB | Mornsun K7805-500R3-LB 5V 500mA 4.75~36Vin | PWR MOD Buck 5V K7805-500R3-LB | U7 | K7805-500R3-LB | PWR MOD Buck 5V K7805-500R3-LB | Digi-key | 2725-K7805-500R3-LB-ND | LCSC | C5198056 |  |  | 1
SOIC_N_16 | USB to full UART with internal crystal | CH340C # UCB UART | U13 | CH340C | CH340C # UCB UART | LCSC | C84681 |  |  |  |  | 1
 |  |  |  |  |  |  |  |  |  |  |  | 90
Approved |  | Notes

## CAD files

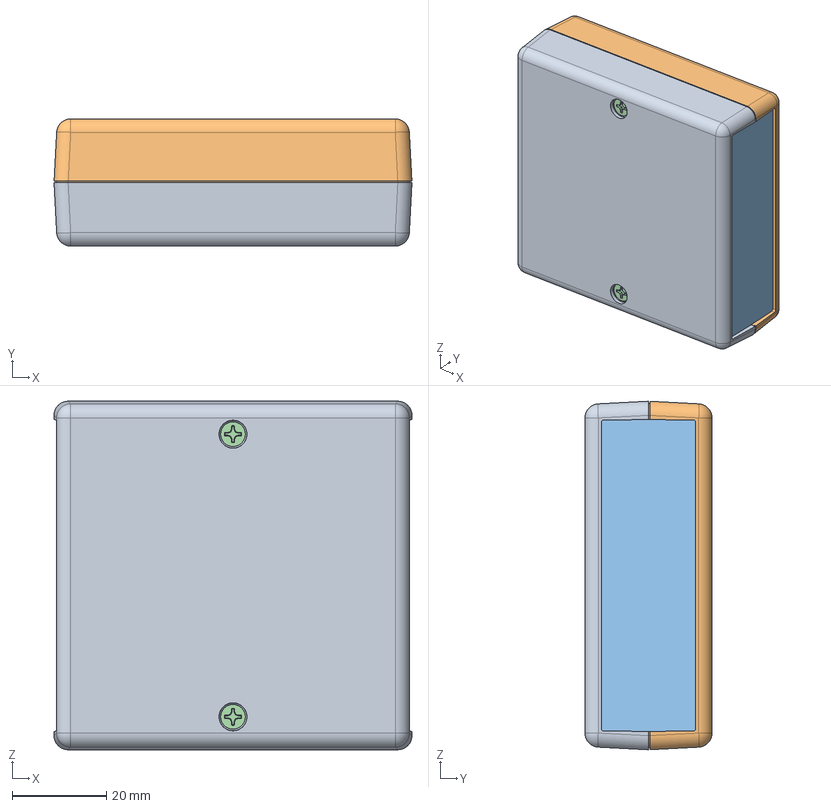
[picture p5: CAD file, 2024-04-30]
Fri3D_IRA_00/1593AR.stp
76.0 x 27.0 x 74.0 mm
1593AR BOTTOM
1593AR TOP
1593AR FRONT FLAT x 2

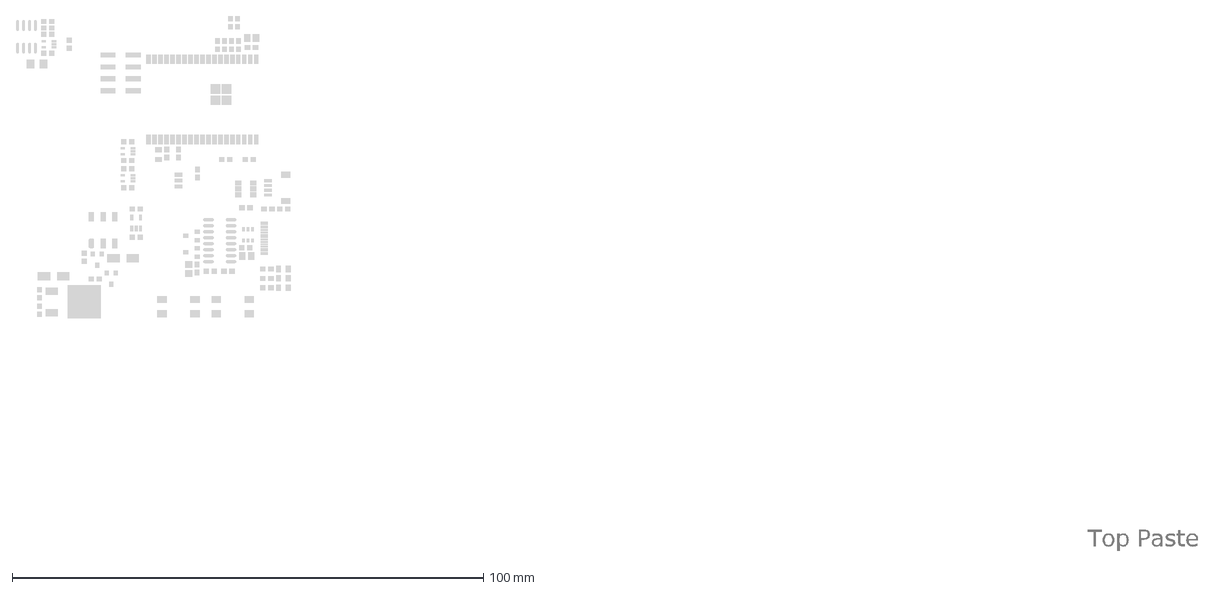
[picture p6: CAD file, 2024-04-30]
Fri3D_IRA_01/Fri3D_IRA_01_PASTE.DXF
Top Paste

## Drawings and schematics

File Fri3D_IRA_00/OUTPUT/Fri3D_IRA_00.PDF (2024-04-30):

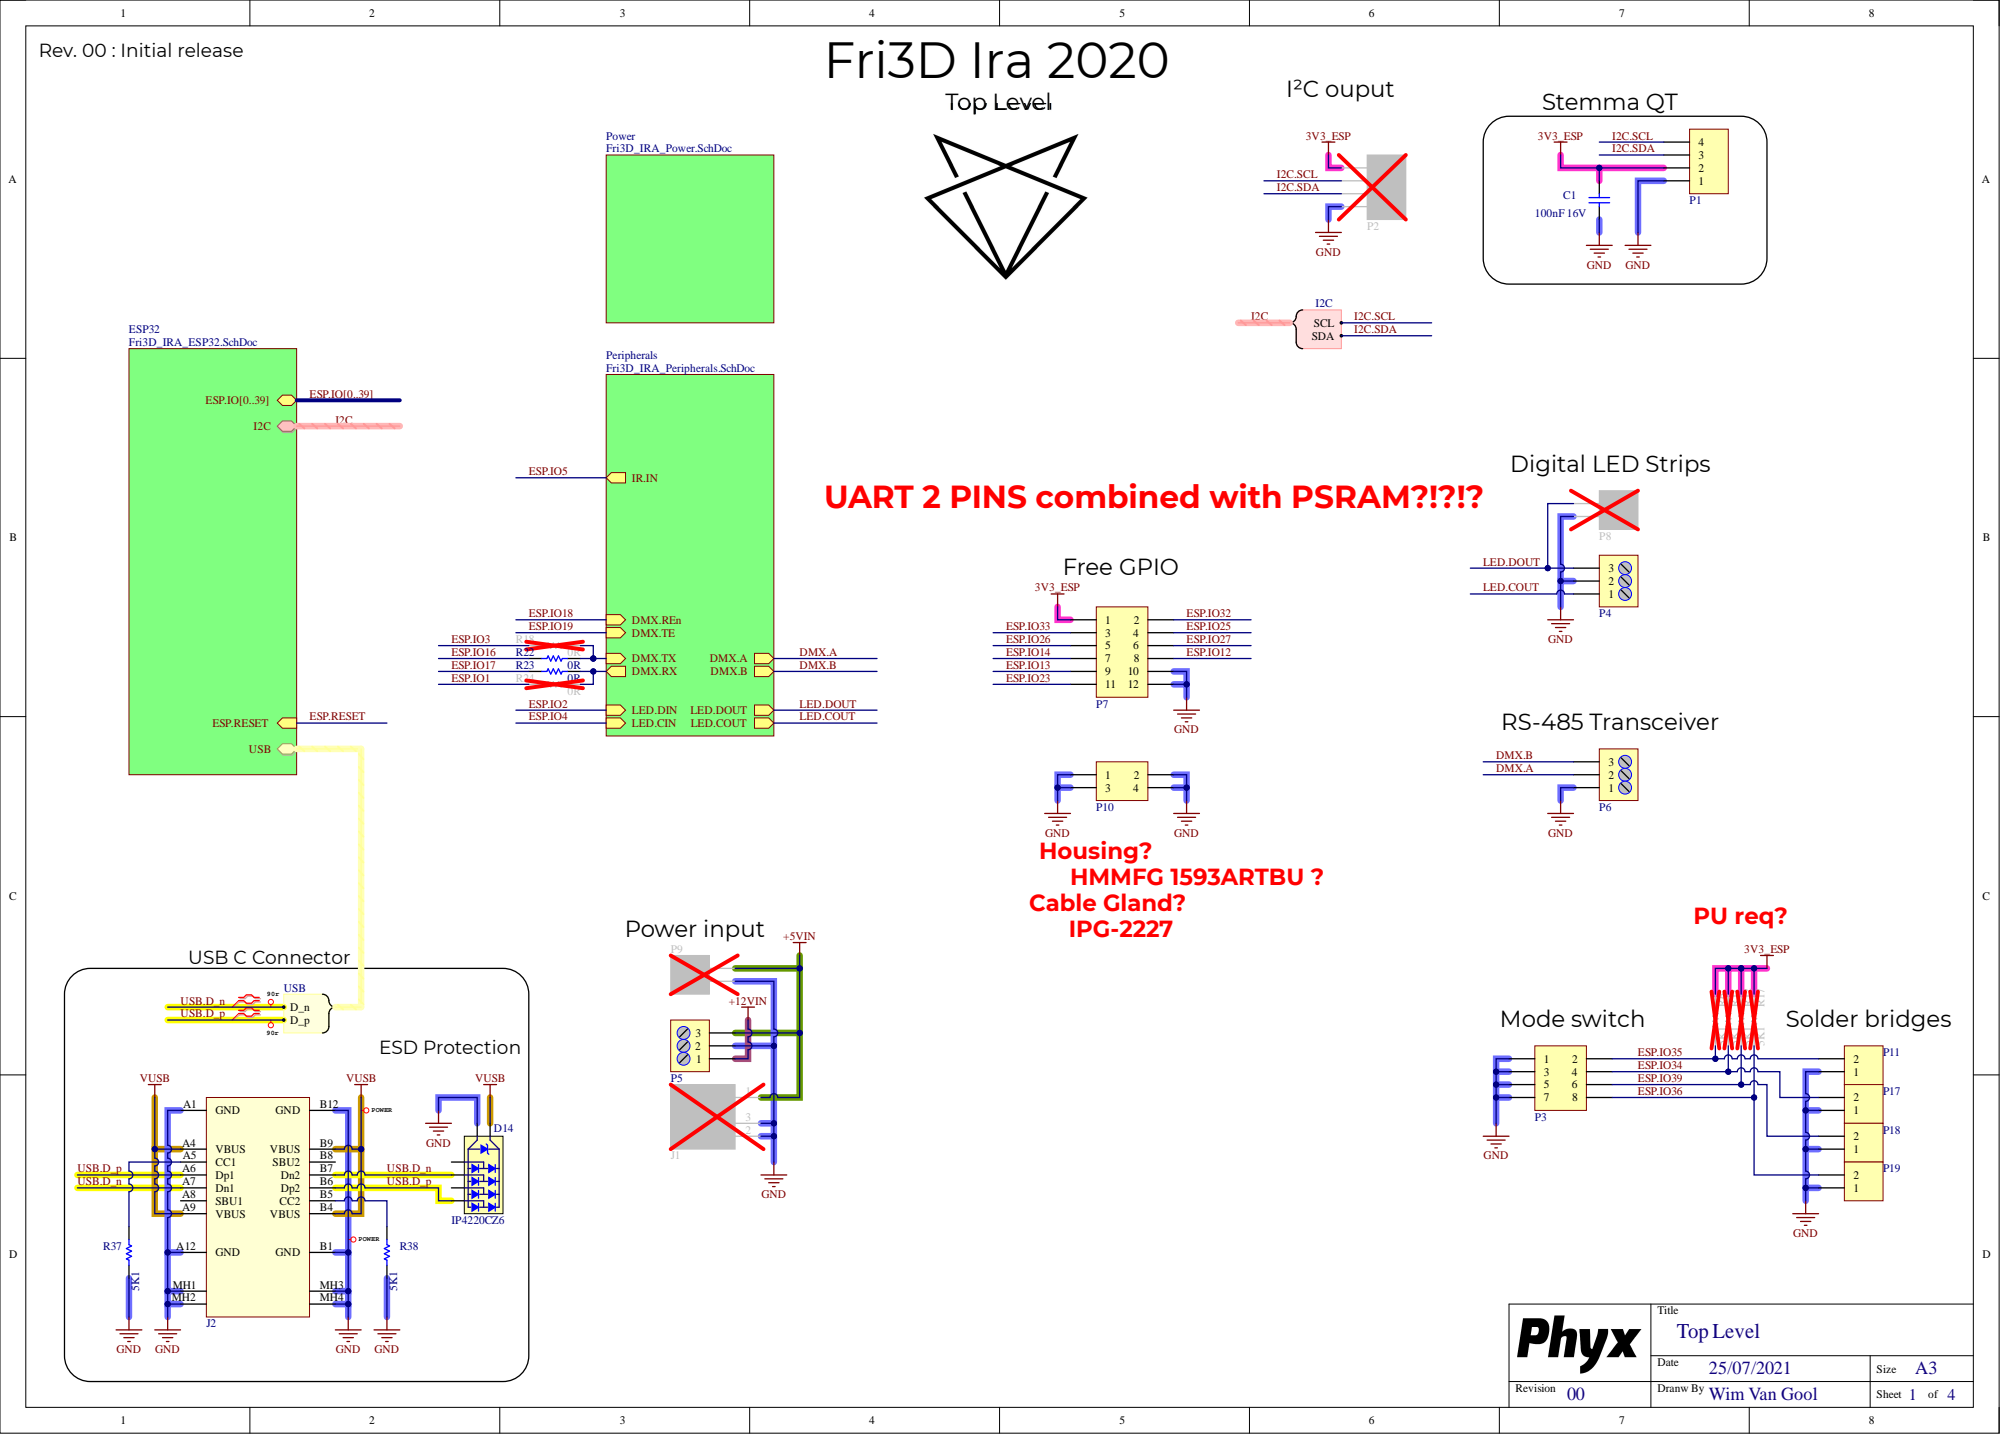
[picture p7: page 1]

UART 2 PINS combined with PSRAM?!?!?

ESP.IO39
ESP.IO36 | 1

MH1 | MH3
MH2 | MH4

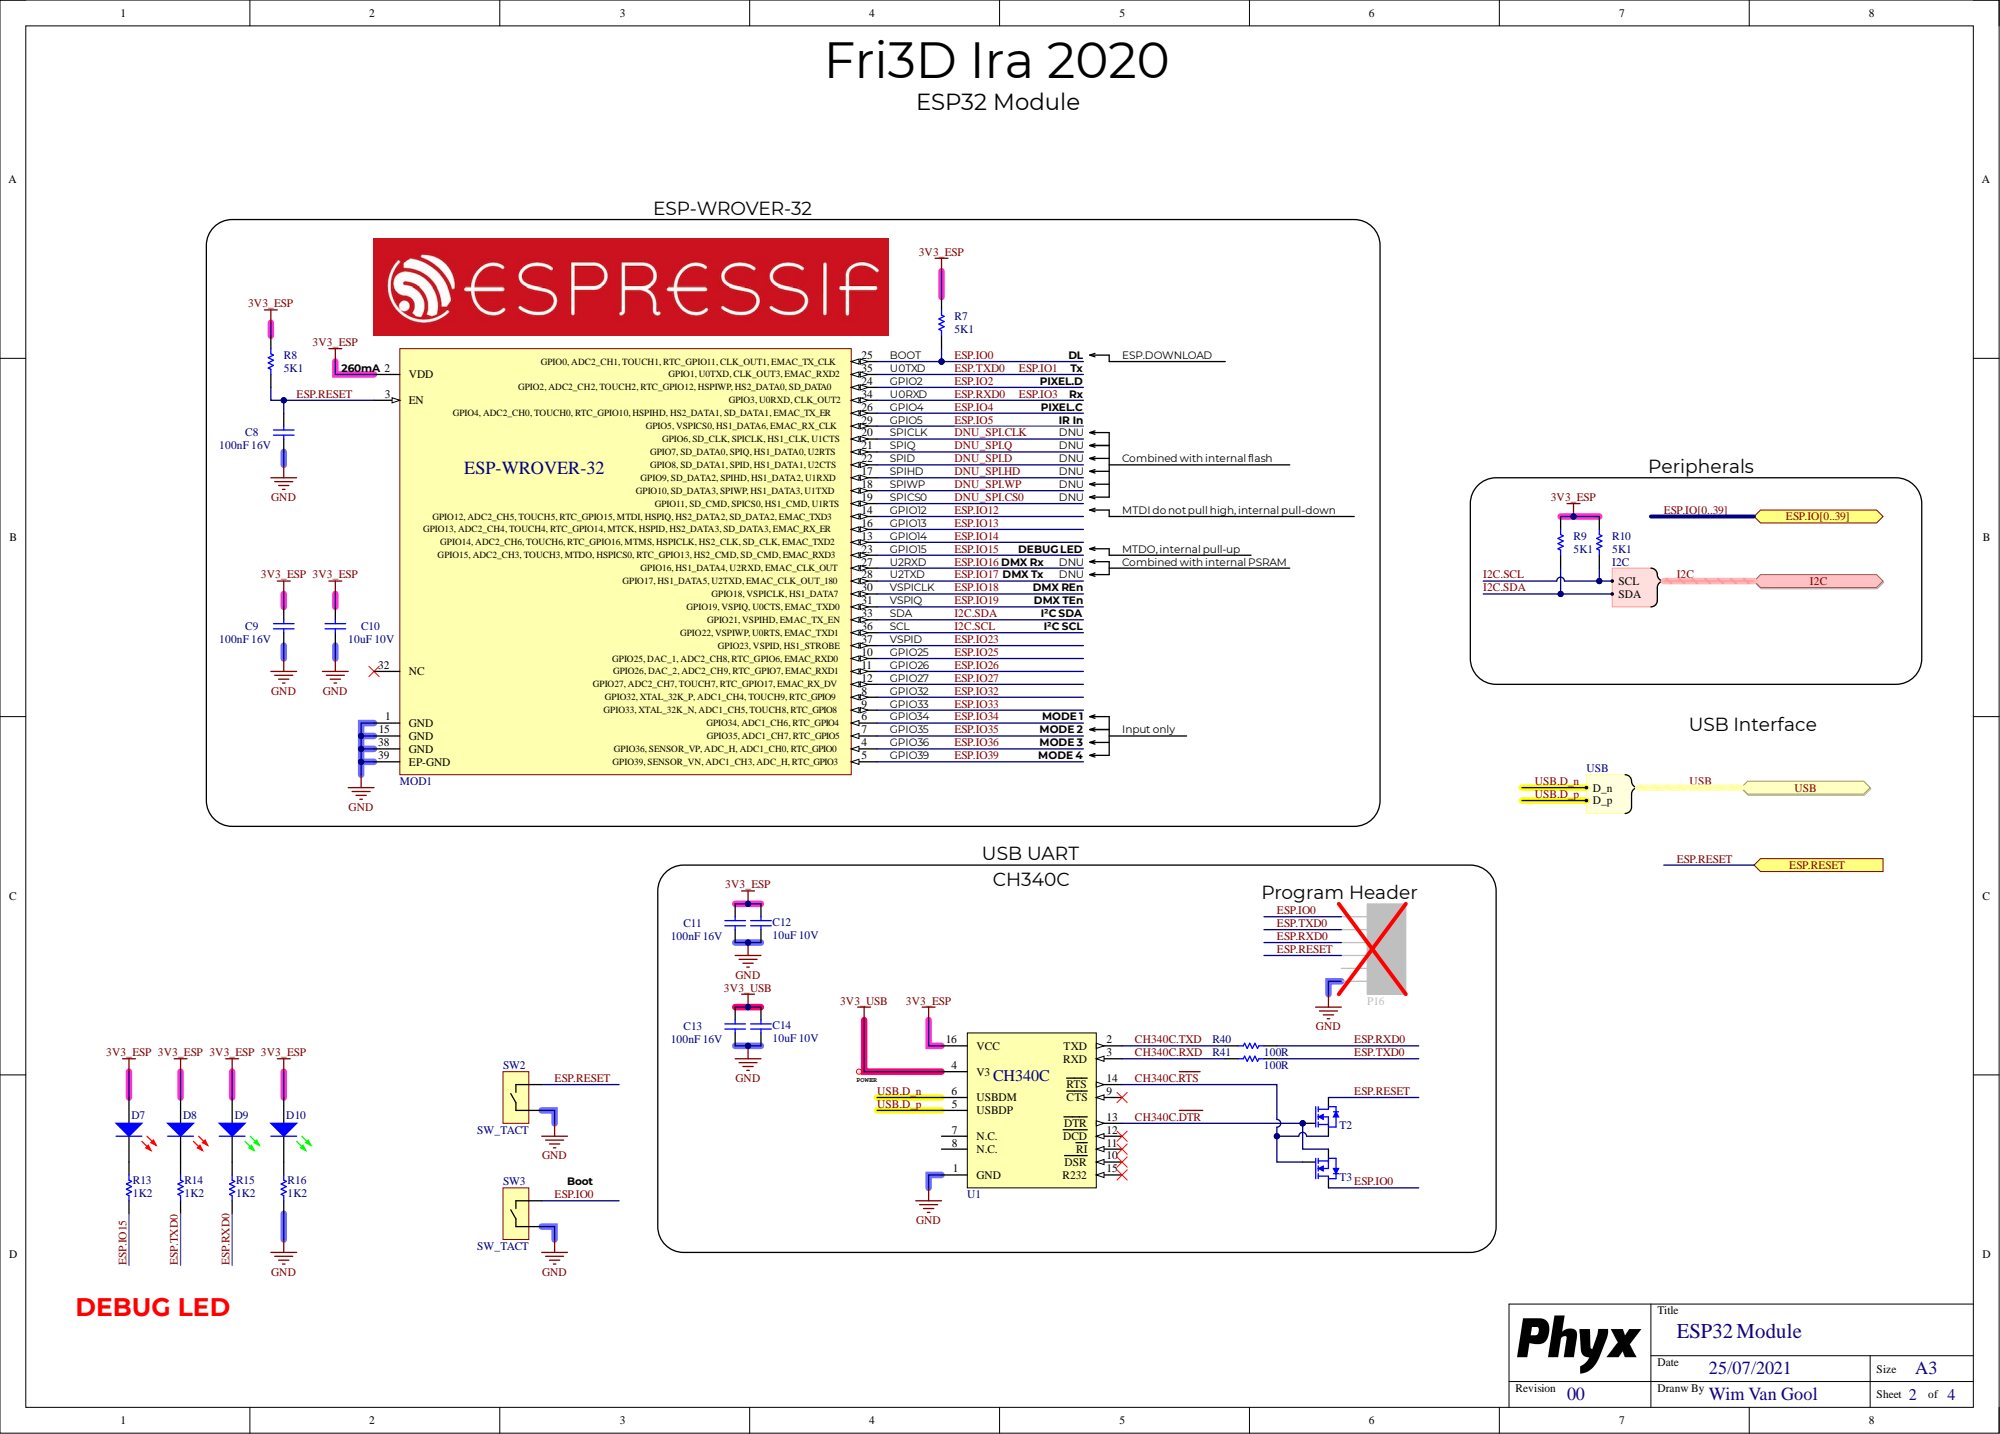
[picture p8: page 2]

1 5
3 8
3 9

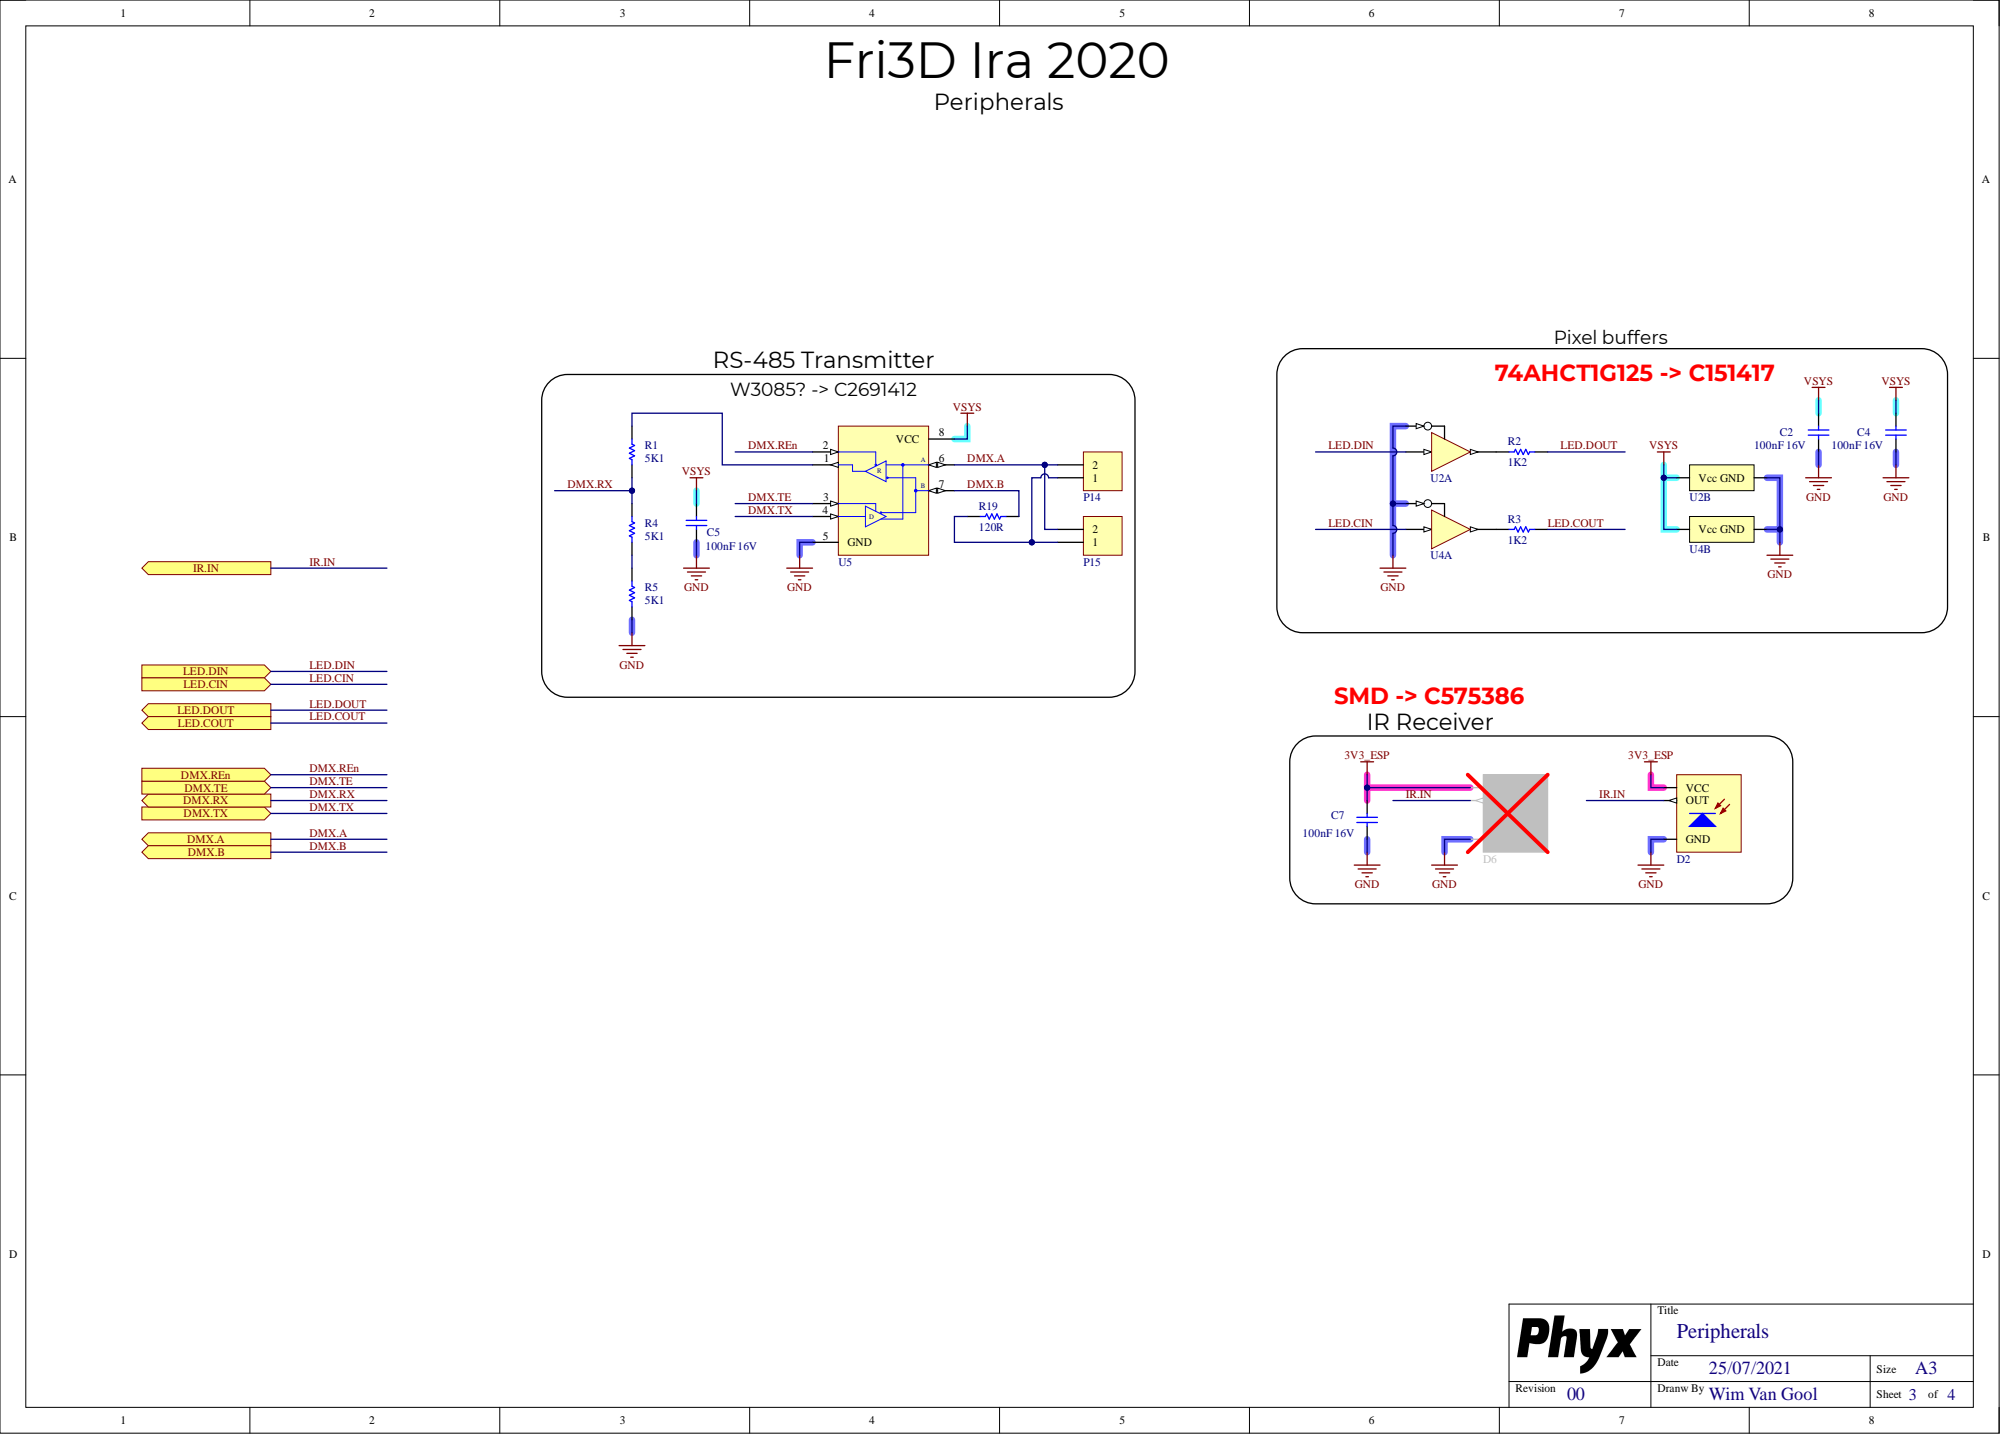
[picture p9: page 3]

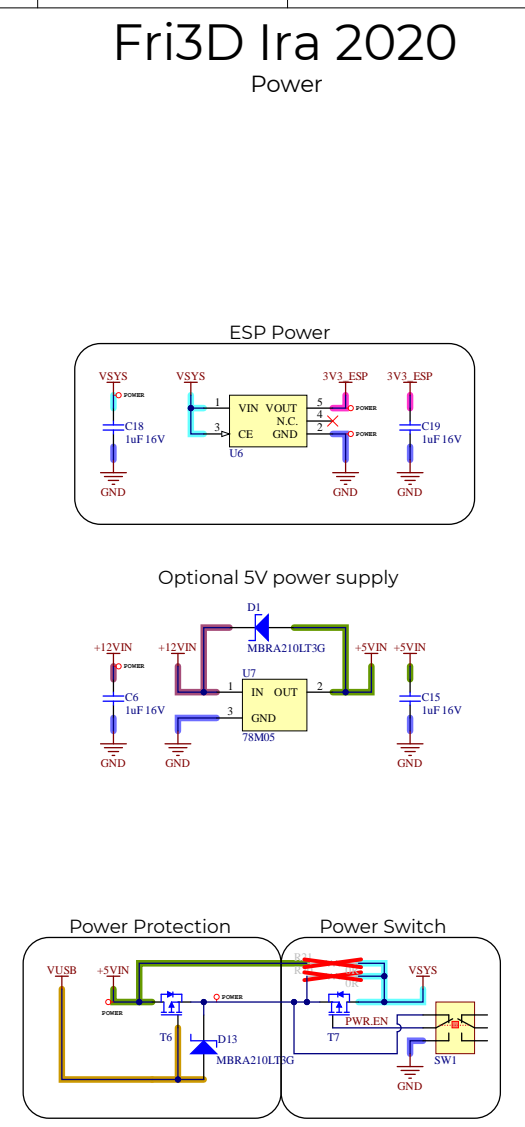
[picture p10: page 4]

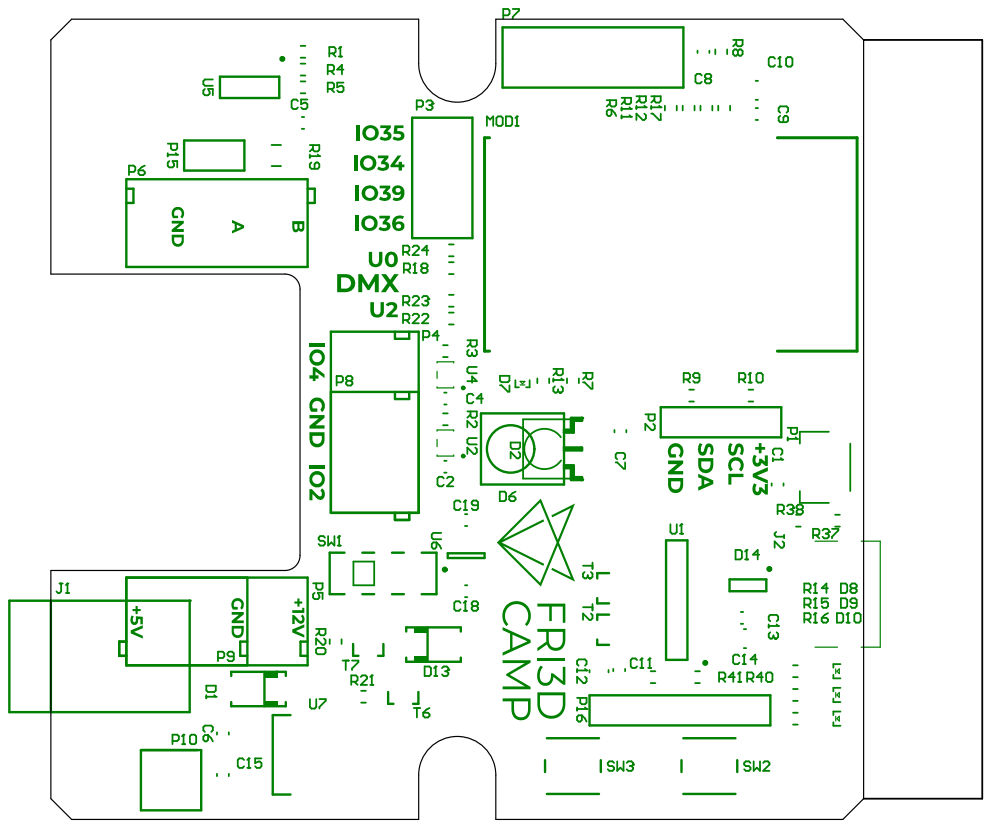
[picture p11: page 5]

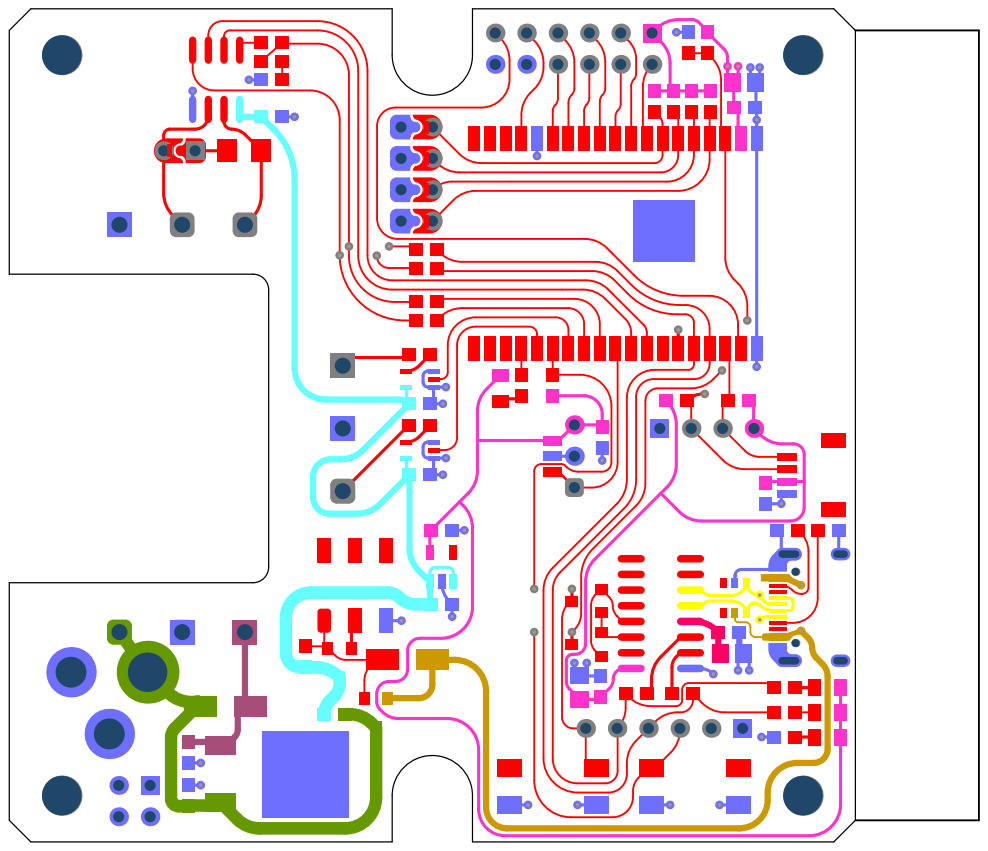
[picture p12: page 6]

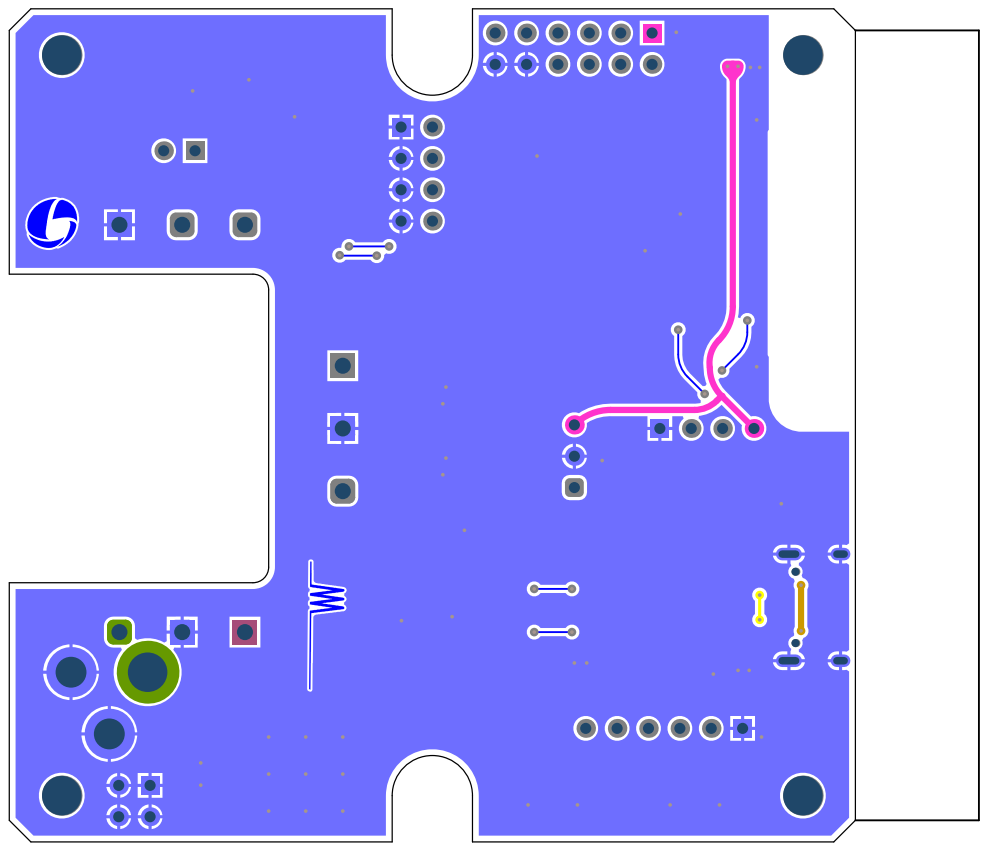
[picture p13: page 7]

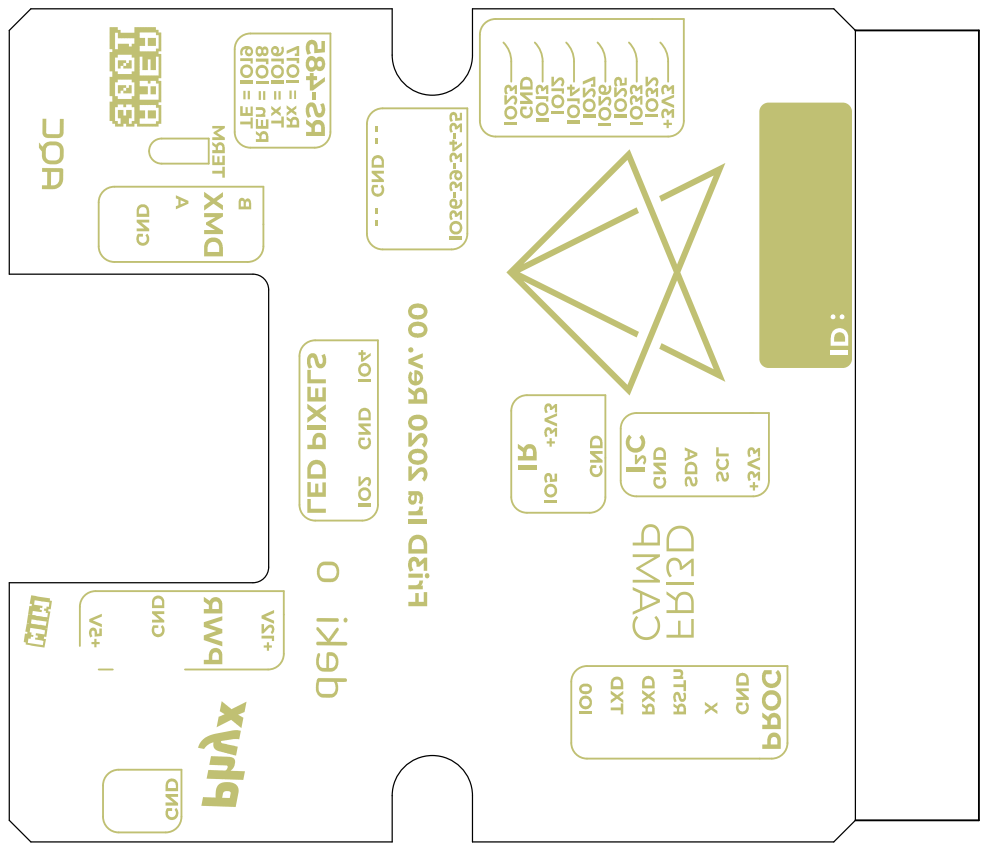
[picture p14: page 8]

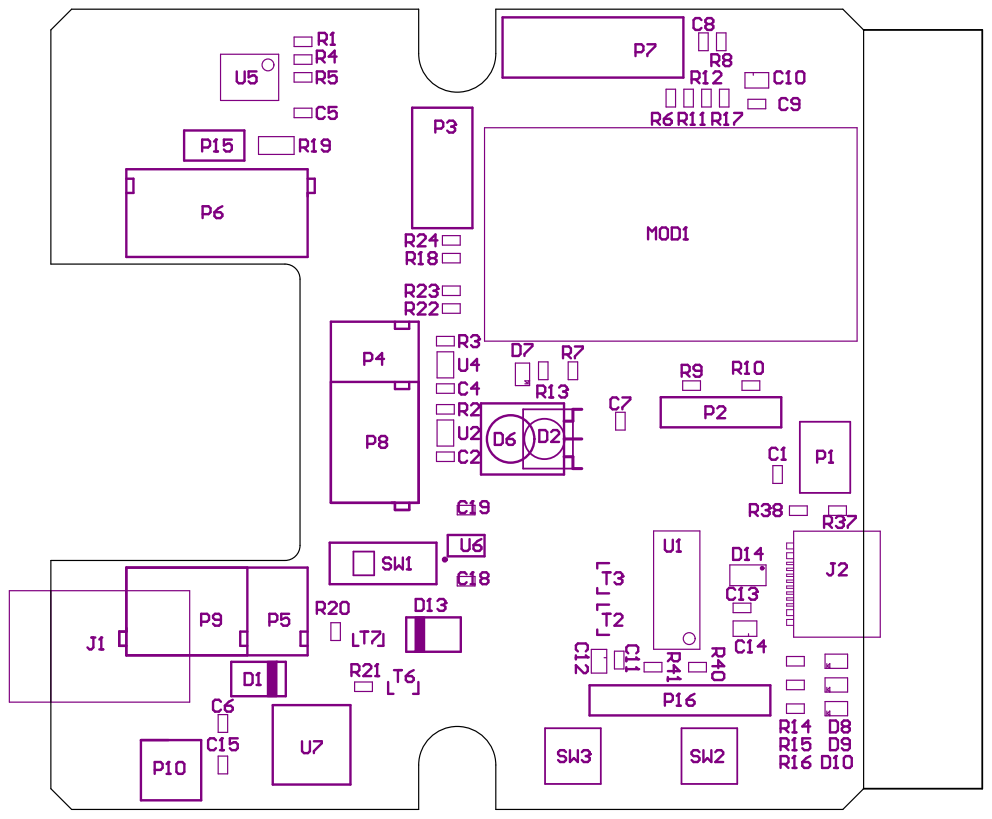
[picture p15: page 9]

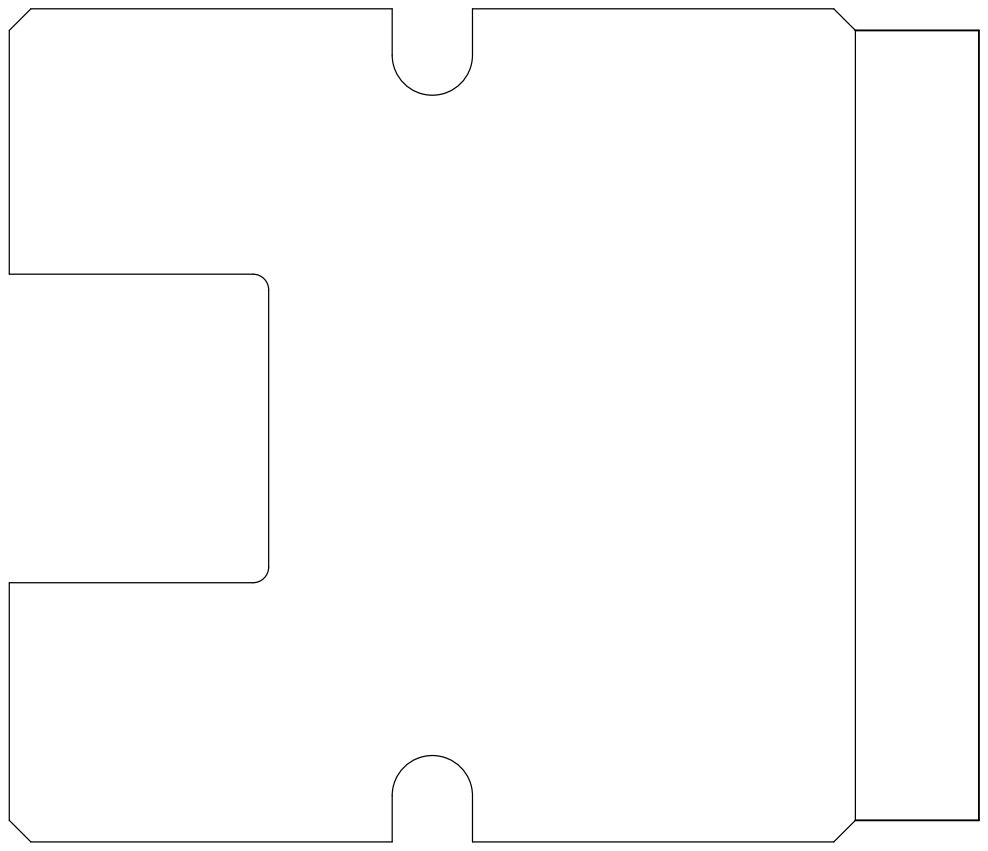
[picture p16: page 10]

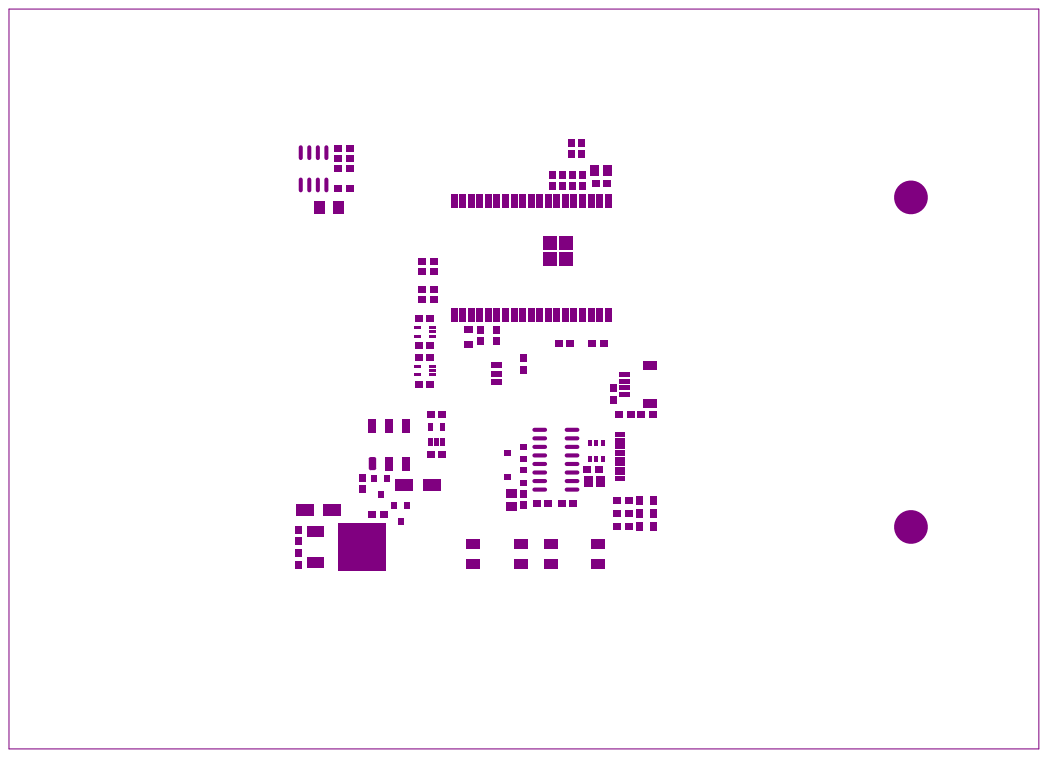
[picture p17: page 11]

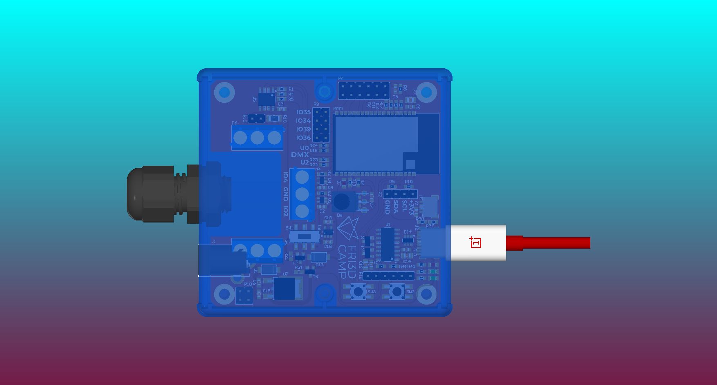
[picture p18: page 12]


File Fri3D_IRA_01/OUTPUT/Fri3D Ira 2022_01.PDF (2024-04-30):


ESP.IO39
ESP.IO36 | 1

MH1 | MH3
MH2 | MH4


1 5
3 8
3 9


Temperature and Humidity sensor











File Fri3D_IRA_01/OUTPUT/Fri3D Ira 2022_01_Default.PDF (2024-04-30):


ESP.IO39
ESP.IO36 | 1

MH1 | MH3
MH2 | MH4


1 5
3 8
3 9


Temperature and Humidity sensor


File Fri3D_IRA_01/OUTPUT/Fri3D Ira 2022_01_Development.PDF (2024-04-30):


ESP.IO39
ESP.IO36 | 1

MH1 | MH3
MH2 | MH4


1 5
3 8
3 9


Temperature and Humidity sensor


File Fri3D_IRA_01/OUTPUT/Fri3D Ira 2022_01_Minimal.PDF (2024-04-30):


ESP.IO39
ESP.IO36 | 1

MH1 | MH3
MH2 | MH4


1 5
3 8
3 9


Temperature and Humidity sensor


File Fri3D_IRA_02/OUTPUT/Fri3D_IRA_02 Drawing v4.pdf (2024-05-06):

Dept.; Technical reference; Created by; Approved by; Document type; Document status; Title; DWG No.; Rev.; Date of issue; Sheet; Koen Buys; SCALE 1:1
